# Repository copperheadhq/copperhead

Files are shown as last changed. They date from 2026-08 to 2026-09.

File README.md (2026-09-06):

<p align="center">
  <a href="https://copperhead.sh">copperhead</a>
</p>

<p align="center">
  
  
  
</p>

**Cursor for circuit boards.** An AI agent that designs, documents, and validates real PCBs from a prompt, working directly on existing KiCad repositories.

<p align="center">
  copperhead agent shell demo
</p>

> **Status: early.** Phase 1 is implemented and the CLI runs. The [technical specification](openspec/specs/SPEC.md) is the source of truth; expect the surface to move before 1.0.

Full documentation lives at [docs.copperhead.sh](https://docs.copperhead.sh).

## What it is

An AI product-development agent for hardware: from a product brief to manufacturable files, firmware, and a build plan.

- **`copperhead create`**: full pipeline from a natural-language brief: spec, architecture, part selection, schematic, first-draft layout, then gerbers, firmware scaffold, and dev plan.
- **`copperhead do "<change>"`**: operates on an existing KiCad repo the way a coding agent operates on a codebase.

It reads and edits real `.kicad_sch` / `.kicad_pcb` files (s-expression text), maintains markdown design docs as memory, propagates every change across all artifacts that reference it, and verifies its own work by running `kicad-cli` ERC/DRC until the checks pass.

## Install

> [!TIP]
> **Most users should not install copperhead by hand.** If you are working inside an AI coding assistant (like Claude Code, Cursor, or Codex), you can install and configure copperhead automatically for your repository by pasting this single line:
> ```text
> Install copperhead for this repo using https://raw.githubusercontent.com/copperheadhq/copperhead/main/agent-install-prompt.md
> ```

If you prefer to install manually:

```bash
npm install -g copperhead   # or: npx copperhead check
```

### Bootstrap script (macOS and Linux)

Prefer a one-command setup? [`install.sh`](install.sh) checks the prerequisites below, installs copperhead (globally via npm, or built from source when run inside a checkout), and verifies the result with `copperhead doctor`:

```bash
./install.sh                # interactive: asks before installing anything
./install.sh --yes          # assume yes to the install prompts
./install.sh --check-only   # report what is missing, install nothing
```

The script is conservative by design: it never runs `sudo` and never edits shell config; whenever it cannot act safely on its own it prints the exact command for you to run instead. Rerunning is safe: on a ready machine it installs nothing and exits 0.

### Requirements

- Node.js ≥ 20
- [KiCad](https://www.kicad.org/) ≥ 8 with `kicad-cli` on PATH (on Windows and macOS, copperhead also searches standard installation directories automatically; override with `COPPERHEAD_KICAD_CLI`)
- One model backend: a locally installed, ChatGPT-authenticated [Codex CLI](https://learn.chatgpt.com/docs/codex/cli), a logged-in [Cursor Agent CLI](#saved-login-cursor-agent) (`agent login`), logged-in Claude Code (see [Saved login](#saved-login-claude-code)), or `ANTHROPIC_API_KEY`/`OPENAI_API_KEY` in the environment. `check` never calls an LLM.

## Quick start

In an existing KiCad repository:

```bash
export ANTHROPIC_API_KEY=...   # or OPENAI_API_KEY; optional: with no key, `copperhead` offers a model picker
copperhead init                # scaffold docs/ from the schematic; idempotent
copperhead                     # interactive agent shell (Claude Code–style REPL)
copperhead demo --tour          # what the agent does (no LLM)
copperhead demo --model cursor # full USB-C breakout create pipeline
# or one-shot:
copperhead do "add reverse-polarity protection on VIN"
copperhead check               # ERC + DRC + doc drift; no LLM, CI-safe
```

Starting from nothing instead? Write a product brief and run `copperhead create --brief brief.md`. The [examples/](examples/) directory has ready-made briefs sorted by difficulty, plus a note on which one is designed to fail.

### Use your existing Codex login

No model API key is needed when Codex CLI is already authenticated:

```bash
npm install -g @openai/codex-sdk   # optional adapter, loaded only for --model codex
codex login status
copperhead do "rename net KEY_DAH to KEY_DASH" --model codex
```

Plain `codex` follows your Codex model configuration. Use `codex:<model-id>` for an explicit model. If the executable is not on `PATH`, set `COPPERHEAD_CODEX_PATH=/absolute/path/to/codex`.
The optional SDK also installs a compatible launcher; for a global install, use
`COPPERHEAD_CODEX_PATH="$(npm root -g)/@openai/codex/bin/codex.js"` as a fallback.

Codex's read-only sandbox prevents native writes but does not confine native reads. Copperhead instructs Codex not to use its own filesystem tools, but the CLI can technically read files such as `.env`. Codex also keeps session logs under `~/.codex/sessions/`; those files are outside Copperhead's transcript-redaction boundary and should be protected according to your local data-retention policy.

## How it works

It's a loop, and it looks a lot like pair-programming, except the codebase is a circuit board.

1. **Start from the docs.** Every decision lives in the design docs, so the agent reads those first and knows the whole design, not just the part in front of it.
2. **Talk through the change.** Describe what you want ("add an external key jack", "cut the sleep current"). The agent proposes the parts and circuit; you push back until the reasoning holds up.
3. **Edit the real files.** The agent writes changes straight into the KiCad schematic and the design docs, using the same part names and net names everywhere so nothing drifts.
4. **Propagate.** Change one value, like a charge current or a pin, and it carries across every doc and schematic that references it. The boring, easy-to-get-wrong step is the one the agent is best at.
5. **Check the work.** The agent runs ERC/DRC, reads the errors back, and fixes them. Nothing is "done" until the tools agree.
6. **Write down why.** Every real decision gets a one-line reason next to it, so the next change doesn't quietly undo it.

Two invariants make this trustworthy:

1. **Nothing starts without a spec.** The agent cannot touch a KiCad file until a validated change proposal exists; the edit tools are structurally unavailable until it does. Every edit is traceable to a documented intent.
2. **Nothing is "done" until the tools agree.** Every file mutation is followed by an ERC/DRC run before the agent reports success.

Spec-gated in, verification-gated out: the design can't drift from its requirements, because drift is a build failure.

## CLI

```text
copperhead init [--path hardware/]   # scaffold docs/ from an existing schematic; idempotent
copperhead do "<change request>"     # the core loop: propose, edit, verify, propagate, commit
copperhead skill list                # registered skills (no LLM)
copperhead skill run generate-report # read-only design report (needs a model)
copperhead check                     # ERC + DRC + doc-drift + spec validation; no LLM calls (alias: verify)
copperhead doctor                    # env preflight: node, kicad-cli, git, openspec, provider credential; no LLM/network
copperhead sync [--dry-run]          # verify the whole design state, resolve drift
copperhead create --brief brief.md   # brief → full output package
copperhead export bom --supplier jlcpcb   # supplier-ready ordering file from docs/BOM.md
copperhead mcp                       # EXPERIMENTAL: serve the gated pipeline to MCP hosts over stdio
```

Global flags: `--repo <path>` (default: cwd) and `--json` for machine-readable output. `--model` is available on `do`, `sync`, `create`, `skill run`, and `doctor`; `--interactive` only on `do` and `create`; `do` also takes `--dry-run`, `--max-turns`, and `--allow-dirty`.

`copperhead create` still uses its own hardcoded stages; those are not yet skills.

`--model` accepts `gpt-5` (OpenAI), `claude` / `claude-<id>` (Anthropic API), `claude-code` / `claude-code:<id>` (Claude Code, saved login), `cursor` / `cursor:<id>` (Cursor Agent CLI, saved login), and `codex` / `codex:<id>` (Codex CLI, saved login). Routing is by prefix; `claude-code` is matched before the `claude` prefix. `compat:<id>` targets any OpenAI-compatible endpoint (Groq, OpenRouter, Gemini, or a local Ollama) via `COPPERHEAD_BASE_URL` and `COPPERHEAD_API_KEY_ENV` - worked examples for each in [`.env.example`](.env.example) and the [configuration reference](https://docs.copperhead.sh/reference/configuration/#model-selection).

### Saved login (Cursor Agent)

`--model cursor` drives the Cursor Agent CLI with your saved login from `agent login`, so you can run copperhead with **no `OPENAI_API_KEY` or `ANTHROPIC_API_KEY`**. Cursor is used purely as a reasoning backend in plan mode: the agent loop, safety gates, and every file edit stay inside copperhead.

```bash
agent status
copperhead do "add reverse-polarity protection on VIN" --model cursor
```

If `agent` is not on `PATH`, set `COPPERHEAD_CURSOR_PATH` to the CLI binary (also available as `cursor-agent` on some installs). Cursor's JSON schema does not report token usage, so run summaries show 0 tokens for `--model cursor`.

### Saved login (Claude Code)

`--model claude-code` drives Claude Code through the [Claude Agent SDK](https://code.claude.com/docs/en/agent-sdk) and reuses your saved login (the `CLAUDE_CODE_OAUTH_TOKEN` from `claude setup-token`), so a Claude subscription runs copperhead with **no `ANTHROPIC_API_KEY`**. Claude Code is used purely as a reasoning backend: the agent loop, its safety gates, and every file edit stay inside copperhead, identical to the other providers.

```bash
claude setup-token                          # while logged into Claude Code
export CLAUDE_CODE_OAUTH_TOKEN=...           # the token setup-token printed
copperhead do "add reverse-polarity protection on VIN" --model claude-code
```

The Claude Agent SDK ships as an optional dependency, so a normal install pulls it in. copperhead loads it only when you select `claude-code`, and prints an actionable error if it is missing (for example after `npm install --omit=optional`), telling you to add it with `npm i @anthropic-ai/claude-agent-sdk`.

copperhead never reads, copies, or logs the credential; the CLI owns authentication. A missing dependency or an unauthenticated install fails with an actionable message and touches nothing.

### Ordering (`export bom`)

`copperhead export bom` turns the drift-checked `docs/BOM.md` into a file a supplier accepts without hand-editing. It is deterministic, LLM-free, and network-free, safe anywhere `check` is, and it reads `BOM.md` (never the schematic) so it inherits the drift guarantee; it refuses to export while `BOM.md` disagrees with the schematic.

```bash
copperhead export bom --supplier jlcpcb                 # JLCPCB assembly CSV → outputs/jlcpcb-bom.csv
copperhead export bom --supplier digikey --boards 25    # DigiKey cart CSV, quantities for 25 boards
copperhead export bom --supplier mouser --spares 15     # Mouser cart CSV, 15% spare parts
```

- `--supplier <jlcpcb|digikey|mouser>` (required). JLCPCB gets the assembly-service format (Comment, Designator, Footprint, LCSC Part #, designators grouped per line); DigiKey and Mouser get cart-upload lists (MPN, manufacturer, quantity, customer reference).
- `--boards <n>` (default 1) and `--spares <percent>` (default 10) set the order quantity: `ceil(perBoardCount × boards × (1 + spares/100))`, raised to `perBoardCount × boards + 2` for passive lines (footprints `R_`/`C_`/`L_`); losing a couple of 0402s to tweezers is the norm, and percentage-only spares under-order low-count passives.
- Rows without an MPN, and rows still flagged `UNVERIFIED`, are excluded from the supplier file and named in a warnings footer on stderr. `--include-unverified` opts the flagged-but-MPN'd rows back in (it never includes MPN-less rows). `create` stage 6 also emits `outputs/jlcpcb-bom.csv` automatically.

`docs/BOM.md` may carry optional `Manufacturer` and `LCSC` columns beyond the base `Refdes | Value | Footprint | MPN | Rationale`; the exporter matches columns by header, so add them when you want them populated in supplier files; `init` scaffolds the base columns only. Only *appending* columns is safe: keep `Refdes | Value | Footprint` first and in that order, because the drift check (`check`/`sync`, which the exporter gates on) reads those three by position, so reordering them makes it compare the wrong cells and refuse the export with a spurious drift message.

Nothing is a black box: decisions land in an append-only `docs/DECISIONS.md`, every run writes a human-readable summary next to its transcript, and a per-run `docs/CHANGELOG.md` narrates the design history.

## MCP server (experimental)

Coding agents are already pointed at KiCad repos through generic file tools, which
means a host agent can rewrite a `.kicad_sch` with no spec gate, no verification,
and no rollback. `copperhead mcp` closes that: it serves the gated pipeline to any
MCP host as five opaque, outcome-level tools — `copperhead_check`, `copperhead_do`,
`copperhead_sync`, `copperhead_init`, `copperhead_doctor` — and nothing finer. There is no file-edit
tool, no raw KiCad tool, and no partial-loop tool to reach around, so a host agent
cannot skip spec-gating or verification by any sequence of calls.

```jsonc
// .mcp.json
{
  "mcpServers": {
    "copperhead": {
      "command": "copperhead",
      "args": ["mcp", "--repo", "/absolute/path/to/your/kicad/project"]
    }
  }
}
```

> **The surface is experimental and unstable.** It declares a `0.` protocol major:
> tool names, inputs, and result shapes may change in any release, and there is no
> registry listing until the stabilization criteria are met. Host configuration for
> Claude Code and generic stdio hosts, the companion skill, the Codex gap, and those
> criteria are all in [`integrations/`](integrations/README.md).

`copperhead_check`, `copperhead_init` and `copperhead_doctor` need no credential; `copperhead_do` and
`copperhead_sync` with `resolve: true` refuse with a typed error naming the missing
environment variable. The server opens no network transport of its own — stdio only,
and LLM calls happen exactly where the CLI already makes them.

## What it is not

- **Not an autorouter.** Routing stays human or delegated; copperhead produces the DRC-clean draft that layout tools optimize from.
- **Not a new editor.** No walled garden; your KiCad install remains the editor.
- **Not the engineer of record.** A human signs off; the agent never claims a design is fab-ready beyond "ERC/DRC clean".

## Simple demo

From a checkout of this repo, run the smallest create-pipeline demo with the USB-C power breakout brief:

```bash
npm run demo:simple
```

The script creates or resumes a git repo at `demo-runs/usb-c-breakout/` and runs:

```bash
copperhead create --brief examples/simple/usb-c-breakout.md
```

Pass normal create flags after `--`, for example `npm run demo:simple -- --model claude`.
If a stage fails, rerun the same command; the demo repo keeps a baseline commit and ignores run transcripts so retries start from the last committed design state.

More briefs, including medium and hard tiers, live in [examples/](examples/).

## Maturity

Honest read of where the current release stands, so you can calibrate before pointing this at a board you care about:

- **Solid.** `init` and `check`/`verify` are deterministic, LLM-free, and covered by the offline test suite against a real KiCad fixture: scaffolding, ERC/DRC, the s-expression reader, drift detection, and fab export all run green in CI.
- **Implemented, not yet proven.** The agent loop (`do`, `sync --resolve`, `create`) is complete and structurally gated, but its acceptance tests need a live model and have not been observed passing end to end. Expect rough edges.
- **Always.** Every mutation runs inside a git snapshot and rolls back if verification fails, so the worst case is a no-op commit, not a mangled schematic. Work on a branch anyway.

## Open source

The entire tool (agent core, prompts, tools) is public under Apache-2.0, built on an open stack (KiCad, kicad-cli, [OpenSpec](https://github.com/Fission-AI/OpenSpec)). Everything it produces is plain markdown and JSON in your own repo: no proprietary formats, no lock-in. This is a Chouhan Industries project, and the same commitment that puts every hardware schematic in public applies to the tool that designs them.

## Contributing

Contributions are welcome; see [CONTRIBUTING.md](CONTRIBUTING.md) for setup and workflow. Note that your first pull request requires signing the [Contributor License Agreement](.github/cla/CLA.md); a bot posts instructions on the PR and signing is a one-time comment.

## Project layout

- [`AGENTS.md`](AGENTS.md): repository instructions loaded automatically by Codex and compatible coding agents; [`CLAUDE.md`](CLAUDE.md) provides the corresponding Claude Code guidance
- [`src/`](src/): CLI ([`cli.ts`](src/cli.ts), [`commands/`](src/commands/)), the provider-agnostic agent loop ([`agent/`](src/agent/)), the `kicad-cli` wrapper and s-expression reader ([`kicad/`](src/kicad/)), and doc/constraint memory ([`memory/`](src/memory/))
- [`integrations/`](integrations/README.md): MCP host configuration and the companion Claude Code skill
- [`test/`](test/): offline suite plus [`fixtures/`](test/fixtures/), a tiny known-good KiCad project
- [`openspec/specs/SPEC.md`](openspec/specs/SPEC.md): the full technical specification, including binary acceptance criteria
- [`openspec/changes/build-copperhead-phase-1/`](openspec/changes/build-copperhead-phase-1/): the implementation plan with proposal, design decisions, capability specs, and task checklist

## License

[Apache-2.0](LICENSE)

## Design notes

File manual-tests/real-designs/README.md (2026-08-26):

# Real designs

Drafting boards nobody wrote for us, and looking at the result next to the drawing a person made of the same circuit.

This is the counterpart to [reference-boards/](../reference-boards/), and the difference is what "correct" means. A reference board's golden is the engine's own pinned output, so a byte diff answers the question completely. Here the golden is a human's schematic, drawn by hand, and the engine places by its own rules. The two sheets never match byte for byte, and a diff of them says nothing at all.

So the comparison splits in two:

- **The netlist is checked by machine.** However differently the two sheets are drawn, they must join the same pins into the same nets. Every net that the source had and the draft lost, or that the draft invented, is reported.
- **The drawing is checked by eye.** Two PNGs, the person's and the engine's, of the same circuit. This is where you find out whether the output reads like a schematic or merely is one.

The designs are read from a local KiCad install at run time and the sweep's outputs land in `manual-tests/runs/` (gitignored). What IS committed lives in [examples/](examples/): the side-by-side output for boards that draft cleanly and whose licences permit redistribution, each with its licence file beside it. Boards whose licences do not permit it stay run-only; `stickhub`, for instance, is CC BY-NC-SA.

## Running it

```bash
npm run realdesigns                 # every project in the corpus
npm run realdesigns -- stickhub     # one project
COPPERHEAD_CORPUS_DIR=/path/to/projects npm run realdesigns
```

The corpus defaults to `/usr/share/kicad/demos`, which ships with KiCad and holds fifteen real projects ranging from a fifteen-part valve amplifier to a 1500-part VME board. Point `COPPERHEAD_CORPUS_DIR` at any directory of KiCad projects to use your own.

Requires `kicad-cli`. PNG rendering additionally needs ImageMagick `convert` and is best effort: some of the larger sheets defeat its default resource limits, and when that happens the schematic and netlists are still written, with a note in the output.

## What each project leaves behind

```
manual-tests/runs/real-designs/<project>/
  source.net                 netlist exported from the real project
  schematic.intent.json      the IR extracted from it
  drawn/board.kicad_sch      what the engine drafted
  back.net                   netlist exported back from the drafted sheet
  render/original*.png       the human's drawing, one PNG per sheet
  render/drawn.png           the engine's drawing
  REPORT.md                  outcome, net comparison, refusal reasons
```

Open `REPORT.md` first; it names which of the two outcomes you got and points at the renders. A refused board still gets its original render and the full finding list, so the boards the engine declines are inspectable too.

## Where the IR comes from

The input is `kicad-cli sch export netlist`, not the `.kicad_sch`. That makes KiCad flatten the hierarchy, resolve the buses, and name every net before we see it, including the ones the designer never named (`Net-(D15-1)`). Reading the schematic directly would mean re-deriving connectivity, and unnamed nets are the majority on a real board: `interf_u` has 303 of its 373 pins on nets carrying no label.

`libsource` supplies each part's lib_id and `sheetpath` supplies its group, so the extraction is deterministic with no LLM involved. The reader lives in [test/support/netlist.ts](../../test/support/netlist.ts), shared with the automated sweep so the two cannot drift.

## The automated half

`test/draft-real-corpus.test.ts` runs the same round trip as an assertion, gated on `COPPERHEAD_TEST_CORPUS=1` and skipped when no corpus is present:

```bash
COPPERHEAD_TEST_CORPUS=1 npx vitest run test/draft-real-corpus.test.ts
```

Its contract is deliberately not "every board drafts". Most real boards legitimately will not, because the engine refuses multi-unit symbols by design. The contract is the weaker and more important one: **draft faithfully or refuse legibly, never silently wrong.** A drafted sheet must partition pins exactly as the source did; a refusal must carry an attributable finding.

That test tells you whether anything broke. This directory is for looking at what the engine actually drew.

## What the corpus has found so far

Against KiCad 10.0.4's demos, eleven of fifteen boards draft with connectivity exact (the remaining four were still sweeping when this was written). Each class of refusal, once understood, became an engine or harness change:

- **Multi-unit symbols** blocked seven of fifteen projects (opamps, gate packs, multi-gang jumpers), and in all seven it was the *only* refusal (#218). The engine now places each unit as its own instance, which cleared the whole set.
- **Symbol resolution** blocked five, all boards drawn against private libraries that were never published. The harness now rebuilds those libraries from the copies every sheet embeds in its `lib_symbols` section ([test/support/embedded-libs.ts](../../test/support/embedded-libs.ts)), so they resolve without being installed; `royalblue54L_feather` and `cm5_minima` draft cleanly because of it.
- **Merged nets at routing** blocked two, `cm5_minima` (+5V shorted to GND) and `interf_u` (/PC-RD to /WR_REG), until #217. Both now draft with connectivity exact.

And the finding that only the renders could have surfaced: **the three boards that draft are correct and unreadable** (#219). All three score a composite of 40 against 85.6 to 92 for the committed reference boards, and `stickhub` carries 367 out-of-frame findings, meaning content placed outside the drawing frame. Its 94 parts come out as one horizontal ribbon on an A0 sheet that is roughly 85% empty, where the designer drew the same circuit densely on A3.

This is the reason the directory exists. The automated sweep passes all three, correctly: its contract is draft faithfully or refuse legibly, and faithfulness is not legibility. Only the side-by-side shows it.

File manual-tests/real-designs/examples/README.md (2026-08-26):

# Committed examples

Real boards the engine drafts cleanly, kept in the repo so the side-by-side comparison is browsable without installing KiCad's demos or running the sweep. Everything here is a verbatim copy of one sweep run's output: the report, the renders, the drafted schematic, and the IR the netlist reduced to.

Each example holds:

```
<board>/
  REPORT.md               outcome and netlist comparison, paths made relative
  schematic.intent.json   the IR extracted from the board's netlist
  drawn/board.kicad_sch   what the engine drafted, openable in KiCad
  render/drawn.png        the engine's drawing
  render/original*.png    the person's drawing, one per sheet
  LICENSE*                the board's own licence, where it ships one
```

## The boards, and why these

Every board here drafts with connectivity exact (lost=0, gained=0), and every one carries a licence that permits redistribution. "KiCad demo" means a board with no licence file of its own that the KiCad project distributes in the `kicad-demos` package; those are included on that provenance.

| Board | Parts | Licence |
| --- | --- | --- |
| `cm5_minima` | 84 | CERN-OHL-S 2.0 (see its `LICENSE.txt`) |
| `complex_hierarchy` | 68 | KiCad demo |
| `ecc83` | 15 | KiCad demo |
| `interf_u` | 24 | KiCad demo |
| `kit-dev-coldfire-xilinx_5213` | 160 | KiCad demo |
| `multichannel` | 114 | KiCad demo |
| `pic_programmer` | 63 | KiCad demo |
| `royalblue54L_feather` | 71 | CERN-OHL-P 2.0 (see its `LICENSE`) |
| `sonde xilinx` | 25 | KiCad demo |
| `tiny_tapeout` | 150 | Apache-2.0 (see its `LICENSE.txt`) |

These licences apply to the boards' design content, including the renders and the drafted schematic derived from it, not to the rest of this repository. `stickhub`, the other board that drafts cleanly, is CC BY-NC-SA and stays out of the repo: run `npm run realdesigns -- stickhub` to reproduce it locally.

## Regenerating

The sweep writes fresh output to `manual-tests/runs/real-designs/` (gitignored):

```bash
npm run realdesigns -- cm5_minima interf_u royalblue54L_feather
```

An example is updated by copying the run output over the committed one and making the `render/` paths in REPORT.md relative. The source projects come from the `kicad-demos` package at `/usr/share/kicad/demos`.

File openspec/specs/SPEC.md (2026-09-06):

# copperhead — Technical Specification

**Cursor for circuit boards.** An AI agent that designs, documents, and validates real PCBs from a prompt, working directly on existing KiCad repositories.

License: Apache-2.0 · Runtime: Node.js ≥ 20 · Language: TypeScript

**copperhead is open source.** The entire tool — agent core, prompts, tools, viewer — is public under Apache-2.0, developed in the open on GitHub with public issues and PRs. It builds exclusively on an open stack (KiCad, kicad-cli, OpenSpec) and produces open, inspectable artifacts: every design decision, constraint, and rationale it writes is plain markdown and JSON in the user's own repo — no proprietary formats, no lock-in, no black box. This is a Chouhan Industries project: the same commitment that puts every hardware schematic in public applies to the tool that designs them. Open source is also the distribution strategy — hardware engineers trust what they can inspect. (Commercial layer, later: hosted agent for private repos; the open core stays complete and usable forever.)

---

## 1. Product definition

### 1.1 What it is

An AI product-development agent for hardware: from a product brief to manufacturable files, firmware, and a build plan. Two modes:

**Mode A — Designer (`copperhead create`).** Input: a product description, requirements, and constraints in natural language. The agent runs the full design pipeline: spec → architecture → part selection → schematic → layout intent → verification → output package.

**Mode B — Co-designer (`copperhead do`).** Operates on an existing KiCad repository the way a coding agent operates on a codebase (the core loop, §4). Mode A is Mode B run repeatedly against a growing repo — same loop, same tools, same verification.

The agent:

- Reads and edits real `.kicad_sch` and `.kicad_pcb` files (s-expression text format)
- Maintains a set of markdown design docs ("docs-as-memory") that describe the design's intent, constraints, and rationale
- Propagates any change across every artifact that references it (schematic, BOM, pinout, docs)
- Verifies its own work by running `kicad-cli` ERC/DRC and iterating until checks pass
- Records a one-line rationale next to every decision so future changes don't silently undo past reasoning

### 1.2 What it is not

- Not an autorouter (Quilter/DeepPCB territory) — routing stays human or delegated
- Not a new editor (Flux territory) — no walled garden; the user's KiCad install remains the editor
- Not the engineer of record — human signs off; the agent must never claim a design is fab-ready beyond "ERC/DRC clean"

### 1.3 Core invariants

1. **Nothing starts without a spec.** The agent cannot touch a KiCad file until a validated OpenSpec proposal exists for the change (`openspec validate --change <id>` passes). The edit tools (`edit_file`, `write_file`) are hard-locked — not prompt-discouraged, but unavailable in the tool list — until the proposal validates. Every edit is therefore traceable to a documented intent.
2. **Nothing is "done" until the tools agree.** Every mutation of a KiCad file must be followed by an ERC (schematic) or DRC (board) run before the agent reports success. If violations exist, the agent reads the report and fixes them or explains why it cannot.

Spec-gated in, verification-gated out: the design can't drift from its requirements, because drift is a build failure.

---

## 2. Architecture

```
┌────────────┐   prompt    ┌─────────────────────────────┐
│  CLI (cmd)  ├────────────►│        Agent core           │
└────────────┘             │  provider-agnostic LLM loop │
                           │ (OpenAI / Claude / Codex)  │
                           └──────┬──────────────────────┘
                                  │ tool calls
              ┌───────────────────┼───────────────────────┐
              ▼                   ▼                       ▼
      ┌──────────────┐   ┌──────────────┐        ┌───────────────┐
      │  File tools  │   │ KiCad tools  │        │  Memory tools │
      │ read/write/  │   │ erc / drc /  │        │ design docs   │
      │ edit/search  │   │ export-svg   │        │ load/update   │
      └──────┬───────┘   └──────┬───────┘        └──────┬────────┘
             ▼                  ▼                        ▼
        .kicad_sch /       kicad-cli               docs/*.md
        .kicad_pcb         (subprocess)            BOM, pinout…
```

### 2.1 Repo layout (this project)

```
copperhead/
├── src/
│   ├── cli.ts              # entry: commander-based CLI
│   ├── agent/
│   │   ├── loop.ts         # tool-use loop, turn budget, retry
│   │   ├── providers/
│   │   │   ├── openai.ts   # GPT-5 via OpenAI SDK (tool calling)
│   │   │   ├── anthropic.ts# Claude via Anthropic SDK
│   │   │   └── codex.ts    # local Codex CLI via official SDK + saved login
│   │   ├── prompts.ts      # system prompt + task templates
│   │   └── tools.ts        # tool schemas + dispatch
│   ├── kicad/
│   │   ├── cli.ts          # kicad-cli wrapper (erc, drc, export svg)
│   │   ├── sexp.ts         # minimal s-expression reader (validation only)
│   │   ├── report.ts       # ERC/DRC .rpt / JSON parser → structured violations
│   │   ├── draft/          # deterministic drafting engine: IR → placement → routing → emission
│   │   ├── legibility.ts   # drawing-quality checker (read-only, no subprocess)
│   │   └── score.ts        # quantitative sheet score: metrics, weights, composite
│   ├── memory/
│   │   ├── scaffold.ts     # `init`: generate docs skeleton from schematic
│   │   └── drift.ts        # doc-vs-schematic consistency checker
│   ├── viewer/             # Phase 2
│   │   ├── server.ts       # express + ws, serves live board view
│   │   └── watch.ts        # chokidar watcher → re-export SVG → ws push
│   └── util/
├── test/
│   └── fixtures/           # tiny known-good KiCad project for tests
├── docs/                   # this spec, architecture notes
├── package.json            # bin: { "copperhead": "dist/cli.js" }
├── tsconfig.json
├── .env.example            # OPENAI_API_KEY= / ANTHROPIC_API_KEY= / CLAUDE_CODE_OAUTH_TOKEN=
└── LICENSE                 # Apache-2.0
```

### 2.2 Target repo layout (user's hardware project)

`copperhead init` establishes/expects this convention:

```
their-board/
├── hardware/
│   ├── <name>.kicad_pro
│   ├── <name>.kicad_sch    # possibly hierarchical, multiple sheets
│   └── <name>.kicad_pcb
├── docs/
│   ├── SPEC.md             # what the device is; top-level constraints & budgets
│   ├── BOM.md              # every part: refdes, MPN, value, package, WHY chosen
│   ├── PINOUT.md           # MCU pin assignment table + strapping/RTC notes
│   ├── SUBSYSTEMS.md       # per-sheet values & reasoning (regulator, charger…)
│   ├── BRIEF.sha256        # originating brief path + SHA-256; created on first successful spec-seed run, preserved thereafter
│   └── LAYOUT.md           # placement/routing intent: keepouts, pours, ESD placement
└── .copperhead/
    ├── config.json         # paths, model, budgets (see §5)
    └── runs/               # transcript of each `do` run (audit trail)
```

---

## 2.5 End-to-end I/O contract

### Inputs (Mode A)

```
copperhead create --brief brief.md
```

`brief.md` — the product brief, free-form markdown:

- **What it is:** "a pocket-size Morse key that types into any device as a Bluetooth keyboard"
- **Requirements:** features, interfaces (USB-C, BLE), user interactions
- **Constraints:** power budget, size envelope, unit cost target, battery life, cert targets
- **Preferences:** MCU family, connector types, no-go parts, assembly method (hand-solder vs SMT fab)

Anything unstated → the agent proposes defaults in SPEC.md and flags them `ASSUMED` for review. Ambiguity resolution is interactive: the agent asks up to N clarifying questions before starting (configurable, 0 for demo mode).

### Outputs (the deliverable package, `outputs/`)

| Artifact | Format | Produced by |
|---|---|---|
| Design docs | SPEC/BOM/PINOUT/SUBSYSTEMS/LAYOUT.md | agent (§2.2) |
| Schematic | .kicad_sch | agent edits, ERC-clean |
| Board | .kicad_pcb | agent edits, DRC-clean |
| **Gerbers + drill** | .zip (per JLC/PCBWay profile) | `kicad-cli pcb export gerbers/drill` |
| **Board outline / enclosure ref** | .dxf, .step | `kicad-cli pcb export dxf/step` |
| **Renders** | .svg (sch + pcb), 3D .png | `kicad-cli export svg`, pcb render |
| **BOM for ordering** | .csv (refdes, MPN, qty, vendor links) | generated from BOM.md |
| **Firmware scaffold** | src/ (per MCU HAL: ESP-IDF / Zephyr / Arduino) | agent, compiles clean |
| **Pin map header** | pins.h — generated from PINOUT.md, single source of truth | drift-checked |
| **Dev plan** | DEVPLAN.md: bring-up steps, test points, what to meter first, risk list, prototype order plan | agent |

Firmware scope: scaffold + pin definitions + driver stubs + one working happy-path (e.g. key press → BLE HID report). "Compiles clean against the vendor toolchain" is the verification gate — same philosophy as ERC/DRC: nothing is done until the toolchain agrees.

### The pipeline (Mode A internally)

**Run-to-completion guarantee:** once `create` starts, it always finishes with the complete output package. Gates are *quality checks the agent must satisfy*, not stops that wait for a human. By default the pipeline is fully autonomous: unstated decisions get `ASSUMED` flags, imperfect layout gets the `Draft quality` label, and the run ends with gerbers, firmware, renders, and DEVPLAN.md on disk — an end product, reviewable as a whole. `--interactive` turns the two human gates (spec approval, pre-export review) back on for users who want them.

```
brief.md
  → SPEC.md (budgets, ASSUMED flags)          [gate: spec is self-consistent]
  → architecture (block diagram in SUBSYSTEMS.md)
  → part selection (BOM.md with rationale)     [gate: check_drift]
  → schematic, sheet by sheet                  [gate: ERC after every sheet]
  → first-draft layout (see below)             [gate: DRC]
  → outputs package                            [gate: all exports succeed]
  → firmware scaffold                          [gate: build passes]
  → DEVPLAN.md
```

Each stage is a `do`-loop run with a stage-specific prompt. State lives in the repo (docs + files), so `create` is resumable: kill it at any stage, re-run, it continues from the docs.

### First-draft layout (explicitly non-optimal, explicitly useful)

The agent produces an **initial placement and routing plan** — correct, not optimal — and says so:

- **Placement:** rule-driven, from LAYOUT.md intent: connectors on edges, decoupling caps at their IC pins, ESD at connectors, antenna keepout honored, crystal next to MCU, user-facing parts (buttons, LEDs) where the brief puts them. Written as actual coordinates into the .kicad_pcb.
- **Routing:** power nets and short critical nets routed by rule (USB differential pair length-matched via KiCad's tools where possible); remaining nets left as ratsnest or routed naively. Every routed net must pass DRC; nothing hand-wavy.
- **Honesty gate:** LAYOUT.md gets a `## Draft quality` section auto-written by the agent, listing exactly what is fine (budgets, keepouts, DRC-clean) and what a human or a specialist tool (Quilter, autorouter) should redo before fab. Non-optimal is acceptable; unlabeled non-optimal is not.
- **Positioning:** this makes layout tools *complements, not competitors* — copperhead produces the DRC-clean draft and constraints file they optimize from.

Delta 4 framing: a first-draft board that passes DRC in an hour vs. a blank canvas that takes a specialist a week. Optimization is iteration; the blank canvas was the bottleneck.

## 2.6 OpenSpec integration — the documentation layer

copperhead adopts [OpenSpec](https://github.com/Fission-AI/OpenSpec) (spec-driven development framework, Node ≥ 20 — same runtime) as the user-facing docs/change-management layer on top of the design docs.

### Two-tier memory model

| Tier | Location | Owner | Contents |
|---|---|---|---|
| **Spec tier (OpenSpec)** | `openspec/specs/` | user-reviewable truth | Requirements & scenarios per capability: power, connectivity, ui, enclosure, firmware. What the product must do and under what constraints |
| **Design tier (copperhead)** | `docs/` + `.copperhead/` | agent working memory | How it's achieved: BOM rationale, pinout, subsystem values, layout intent — plus the machine-readable constraint memory (below) |

### Constraint memory

The agent maintains `.copperhead/constraints.json` — a live, machine-readable registry built **simultaneously with the docs**: every time a constraint is stated (brief), assumed (flagged `ASSUMED`), or discovered (datasheet), it lands in both the human doc and the registry in the same tool turn:

```json
{
  "power.sleep_current_uA":  { "max": 25,  "source": "openspec/specs/power/spec.md#R2",
                               "affects": ["U2", "R7-absent", "GPIO-pullups"] },
  "rf.antenna_keepout_mm":   { "min": 5,   "source": "docs/LAYOUT.md", "affects": ["zone:top"] },
  "pins.strapping":          { "forbidden": ["GPIO0","GPIO3","GPIO45","GPIO46"],
                               "source": "esp32-s3 datasheet §2.4" }
}
```

Loaded into every run's system prompt; `check` validates the design against it mechanically where possible (leakage sums, keepout geometry, forbidden pins). The `affects` field is what makes propagation reliable — change a constraint and the agent knows exactly which parts to revisit.

An `affects` item that targets an artifact that does not exist yet (schematic, board, or BOM recorded before their pipeline stage) opens no revisit obligation at record time — it is marked `deferred` in the registry instead, and the obligation re-opens automatically at the start of the first run where the artifact exists. This keeps early docs-only stages from burning turns on ceremonial "not yet created" resolutions without losing the reconciliation guarantee: the revisit still happens, at the moment it can actually change the design.

### Change workflow (OpenSpec propose → apply → archive)

- `copperhead do "<request>"` first generates `openspec/changes/<id>/` (proposal.md, spec deltas, tasks.md), then implements against it; the ERC/DRC-clean commit archives the change. Every hardware change gets a paper trail: *why → what spec changed → what files changed → verification result*
- `copperhead create` seeds `openspec/specs/` from the brief as stage one — requirements with scenarios ("Given the device sleeps, when idle 1 year, then battery ≥ 20%") become the testable source that SPEC.md budgets derive from
- In `--interactive` mode, the human approves the proposal; in autonomous mode it's written and auto-approved with an `AUTO` marker — reviewable after the fact, never lost
- `openspec validate` runs inside `copperhead check`

### Trigger mechanics

OpenSpec is never user-triggered; copperhead drives it as subprocess tools (same pattern as kicad-cli):

| When | copperhead runs | Effect |
|---|---|---|
| `init` / `create` start | `openspec init` (once) | Scaffolds `openspec/`; agent seeds `specs/` from the brief |
| `do` — plan step | agent writes `openspec/changes/<id>/`, then `openspec validate --change <id>` | **Edit tools stay locked until the proposal validates.** The plan step *is* the proposal |
| `do` — after ERC/DRC pass + commit | `openspec archive <id>` | Deltas merge into `specs/`; change record closed by the same code path that committed |
| `check` | `openspec validate` | Part of the standard gate set |
| `--interactive` only | pause after proposal validation | Human y/n before edits unlock — the single manual trigger |

This kills the last "docs drift" failure mode: requirements (openspec) → budgets (SPEC.md) → constraints (constraints.json) → design (KiCad) form a chain where every link is checked by tooling, not memory.

## 3. CLI surface (Phase 1)

```
copperhead [repl] ["<change request>"] [--model …] [--allow-dirty]
    Interactive agent shell (default when no subcommand is given).
    Claude Code–style prompt loop on a TTY: each line runs one
    `do`-equivalent change (same gates, including the AC-3.8 dirty-tree
    refusal and the same off-by-default `--allow-dirty` escape hatch),
    then returns to the prompt.
    Slash commands: /help, /demo, /examples, /status, /check, /parts, /nets,
    /bom, /sync, /drift, /constraints, /openspec, /config, /git, /runs, /last,
    /model, /version, /clear, /quit. Inspect commands are verify-only (no LLM
    resolve / create). An optional first request runs before the loop. Non-TTY
    without a request refuses and points at `copperhead do`. With no model
    configured anywhere, a TTY session offers an interactive picker (also
    reachable later via /model). Session output mirrors to
    `.copperhead/runs/repl-<ts>.log` with AC-4.1 redaction applied.

copperhead demo [--tour] [--model …] [--dir <path>]
    Print a short tour of what the agent does (`--tour`), or scaffold
    `demo-runs/usb-c-breakout/` and run the create pipeline against the
    packaged USB-C power breakout brief (same as `npm run demo:simple`).

copperhead create --brief brief.md   # Mode A: full pipeline (§2.5)
copperhead init [--path hardware/]
    Detect .kicad_sch/.kicad_pcb, parse symbols/footprints/nets,
    generate docs/ skeleton pre-filled with the real BOM and pinout
    extracted from the schematic. Idempotent; never overwrites
    hand-edited docs without --force.

copperhead draft schematic [--json]
    Deterministically draft the schematic from its declared intent
    (schematic.intent.json): the engine computes every coordinate, wire,
    label, power symbol, and group box. No LLM, no network. Exits non-zero
    with numbered findings on a refused intent and writes nothing.

copperhead score schematic [--json]
    Quantitative drawing-quality score for the sheet: per-metric breakdown,
    weights, contributions, and the composite. Advisory only — the exit code
    is 0 regardless of the composite. No LLM, no network.

copperhead do "<change request>" [--model codex|gpt-5|claude] [--max-turns N]
    The core loop. See §4.

copperhead skill list
    Print registered skills and whether each is available. LLM-free, network-free,
    and does not create a run transcript/directory.

copperhead skill run <name> [--scope power|all] [--model …]
    Run a skill (currently `generate-report`) via the nested sub-run. Needs a
    model, same as `do`. Does not snapshot or commit.

copperhead check          (alias: copperhead verify)
    Run ERC + DRC + doc-drift check; exit non-zero on violations.
    No LLM calls. Usable as CI step / pre-commit hook.

copperhead sync [--dry-run]
    Verify the entire design state for inconsistencies — doc tables vs
    schematic, constraints.json vs docs and openspec specs, PINOUT.md vs
    pins.h, DECISIONS/CHANGELOG coverage — then resolve the drift via a
    spec-gated agent run (same gates as `do`). Truth precedence: KiCad
    files are ground truth for as-built facts; openspec specs and SPEC.md
    budgets are ground truth for requirements. An inconsistency that
    implies a requirement violation is flagged for the human, never
    silently rewritten. `--dry-run` prints the full inconsistency report
    and writes nothing. Idempotent: a second run finds nothing to do.

copperhead mcp [--repo <path>]            # EXPERIMENTAL
    Serve the gated pipeline to MCP hosts over stdio as five opaque,
    outcome-level tools (copperhead_check / _do / _sync / _init / _doctor).
    No file-edit, raw-KiCad, or partial-loop tool is exposed, so a host
    agent cannot skip spec-gating or verification by any sequence of
    calls; every mutating tool runs the same loop the CLI runs. The
    surface declares a `0.` protocol major and is unstable: tool names,
    inputs, and result shapes may change in any release. stdio only — the
    server opens no network transport, and LLM calls happen exactly where
    the CLI already makes them.

copperhead explain <refdes|net|pin>       # stretch
    Answer "why is R7 here?" from docs + schematic context.

copperhead watch                          # Phase 2
    Start the live viewer (see §6).
```

Global flags: `--repo <path>`, `--dry-run` (propose diff, don't write), `--json` (machine-readable output).

---

## 4. The agent loop (`copperhead do`)

### 4.0 The workflow in plain words (canonical description — use in README/pitch)

It's a loop, and it looks a lot like pair-programming, except the codebase is a circuit board.

1. **Start from the docs.** Every decision lives in the design docs, so the agent reads those first and knows the whole design, not just the part in front of it.
2. **Talk through the change.** Describe what you want ("add an external key jack", "cut the sleep current"). The agent proposes the parts and circuit; you push back until the reasoning holds up.
3. **Edit the real files.** The agent writes the changes straight into the KiCad schematic and the design docs, using the same part names and net names everywhere so nothing drifts.
4. **Propagate.** Change one value, like the charge current or a pin, and it carries across every doc and the schematic that references it. This is the boring, easy-to-get-wrong step the agent is best at.
5. **Check the work.** The agent runs ERC/DRC, reads the errors back, and fixes them. Nothing is "done" until the tools agree.
6. **Write down why.** Every real decision gets a one-line reason next to it, so the next change doesn't quietly undo it.

§4.1 below is this loop made precise; §2.6 adds the OpenSpec proposal wrapper around steps 1–2 and the constraint registry behind steps 4–5.

### 4.1 Sequence

1. **Load memory.** Read all `docs/*.md` + the schematic file list into the system context. Docs are small by design (< ~2k lines total); include them whole.
2. **Plan.** Agent states, in one short block: what will change, which files are affected, which constraints are at risk (e.g. sleep-current budget).
3. **Edit.** Agent uses tools to modify KiCad files and docs. Edits to `.kicad_sch`/`.kicad_pcb` are **text edits on the s-expression source** (search/replace with context anchors) — no full-file regeneration, ever. Same net names and refdes everywhere.
4. **Verify.** Agent runs `run_erc` (always) and `run_drc` (if the .kicad_pcb changed). Parses violations.
5. **Repair.** If violations: fix and re-run, up to `maxRepairCycles` (default 5). If still failing: revert to the pre-run snapshot and report failure with the violation list.
6. **Propagate.** Agent runs `check_drift`; any doc that references a changed value/part/pin must be updated in the same run.
7. **Rationale.** Every non-trivial decision gets a one-line "why" written into the relevant doc.
8. **Commit.** `git commit` with a structured message (`copperhead: <request>\n\n<summary of edits + verification result>`). Requires clean working tree at start (§7 safety).

### 4.2 Tool schemas

| Tool | Signature | Notes |
|---|---|---|
| `read_file` | (path) → text | Repo-relative, sandboxed to repo root |
| `edit_file` | (path, old_string, new_string) → ok | Exact-match anchored replace; fails if not unique |
| `write_file` | (path, content) → ok | New files only (docs); refuses to overwrite .kicad_* |
| `search` | (regex, glob?) → matches | ripgrep-style over repo |
| `list_symbols` | (sch_path) → [{ref, value, footprint, sheet}] | From s-expression parse |
| `list_nets` | (sch_path) → [net names] | |
| `run_erc` | () → {violations: [...]} | `kicad-cli sch erc --format json --exit-code-violations` |
| `run_drc` | () → {violations: [...]} | `kicad-cli pcb drc --format json --exit-code-violations` |
| `export_svg` | (sch\|pcb) → path | For viewer + before/after diffing |
| `check_drift` | () → [{doc, claim, actual}] | Compares doc tables (BOM/pinout) against parsed schematic |
| `generate_report` | (scope?: power\|all) → report | Skill: nested read-only sub-run; ERC/DRC/drift/nets. Always in the catalog. |

### 4.3 System prompt — key rules (verbatim requirements)

- You are a hardware design agent working on real KiCad source files. Edit s-expressions surgically; never regenerate a whole file.
- You cannot edit any file until your change proposal validates (§1.3 invariant 1). Write the proposal first; the edit tools appear only after it passes.
- The design docs are the memory. Read them before proposing anything; update them with everything you change.
- Hold **all** constraints simultaneously: electrical budgets (e.g. sleep current), voltage ranges, package availability, strapping pins, RTC-capability, antenna keepouts. A part that satisfies the obvious constraint but violates a budget is a bug.
- Check the MCU strapping table before assigning any pin. Check quiescent/leakage current of every part against the power budget in SPEC.md.
- Nothing is done until ERC (and DRC when applicable) passes. Read the violation report; do not guess.
- Write a one-line rationale next to every decision. If you remove a part, record why the absence is intentional (a missing pullup can look like a mistake).
- If a request would violate a documented budget or constraint, stop and say so — do not silently comply.

### 4.4 Provider abstraction

```ts
interface Provider {
  chat(messages: Msg[], tools: ToolSchema[], opts): Promise<Turn>;
}
```

- `openai.ts`: GPT-5 via chat completions + tool calling (hackathon shared key)
- `anthropic.ts`: Claude via messages API + tool use
- `codex.ts`: locally installed Codex CLI via the official SDK and saved `codex login` authentication; Codex runs read-only and returns structured Copperhead tool requests
- `claude-code.ts`: saved-login Claude Code via the Claude Agent SDK: a reasoning-only backend (no SDK tools, built-ins disabled, isolated cwd) mapped onto the single-turn `Provider` seam so the loop stays the driver. Selected by `--model claude-code` / `claude-code:<id>` (routed ahead of the `claude*` prefix); needs no `ANTHROPIC_API_KEY` (uses `CLAUDE_CODE_OAUTH_TOKEN` / the logged-in CLI); never falls back to a keyed provider. `@anthropic-ai/claude-agent-sdk` ships as an `optionalDependency` (its `@anthropic-ai/sdk >=0.93.0` peer is satisfied by copperhead's bumped core SDK), lazily imported and only loaded when `claude-code` is selected.
- `cursor.ts`: saved-login Cursor Agent CLI subprocess (`agent login`), reasoning-only (plan mode, sandbox, isolated workspace, JSON tool protocol, session resume via `--resume`). Selected by `--model cursor` / `cursor:<id>`; needs no model API keys; never falls back to a keyed provider. Optional `COPPERHEAD_CURSOR_PATH` (default `agent` on PATH).
- `openai.ts` compatible-endpoint mode: `--model compat:<id>` points the same provider at any OpenAI-compatible endpoint (Groq, OpenRouter, Gemini's compat endpoint, a local Ollama) via `baseURL` + `apiKeyEnv` (config, or `COPPERHEAD_BASE_URL` / `COPPERHEAD_API_KEY_ENV`). Only the `compat` route reads `baseURL`, so a stray value never redirects a `gpt-5` run; a loopback endpoint needs no credential.
- Selection: `--model` flag > `COPPERHEAD_MODEL` env > config.json > the available key, but **only when exactly one of `OPENAI_API_KEY`/`ANTHROPIC_API_KEY` is set**; with two or more present and no explicit selection, resolution refuses with an actionable error rather than silently favoring one (breaking change from "first key wins")
- All providers must pass the same integration test on the fixture repo

### 4.5 Budgets & failure modes

- `maxTurns` default 40; `maxRepairCycles` 5; per-run token budget logged
- On turn-budget exhaustion in an attended (TTY) run: print run stats (turns, files touched, open obligations, token usage) and ask whether to continue with more turns; declining, or a non-TTY run, fails as below. The extension can repeat; each is a fresh decision with fresh numbers.
- On any unrecoverable failure: preserve the touched work as a git stash entry named `copperhead failed run <run-id>`, restore the snapshot, print the stash ref and transcript path, exit 1
- Rate-limit (429): exponential backoff ×3, then fail over to the other **keyed** provider (`openai` ↔ `anthropic`) if a key exists; saved-login providers (`codex`, `claude-code`, `cursor`) never fail over to a keyed or alternate provider
- Nested skill provider turns use the same bounded timeout and 429 backoff policy. A provider error inside a skill becomes a failed tool envelope, so it cannot escape the parent loop and bypass its failure/rollback path.
- The Anthropic provider marks `cache_control` breakpoints (system prompt, last tool, last message block) so the resent conversation prefix is cached; reported input tokens include cache reads/writes

---

## 5. Config (`.copperhead/config.json`)

```json
{
  "schematic": "hardware/open-telegraph.kicad_sch",
  "board": "hardware/open-telegraph.kicad_pcb",
  "docs": "docs/",
  "model": "gpt-5",
  "maxTurns": 40,
  "stageMaxTurns": { "spec-seed": 60 },
  "budgets": { "sleep_current_uA": 25 }
}
```

`budgets` is free-form; keys are surfaced verbatim into the system prompt so the agent treats them as hard constraints. `stageMaxTurns` is optional: per-stage turn budgets for the create pipeline, keyed by stage name; stages without an entry use `maxTurns`.

---

## 6. Phase 2 — Live viewer (`copperhead watch`)

The "Cursor feel": see the board change as the agent works.

- Express server on `localhost:3663`, single-page app (no build step; one HTML file)
- Left pane: chat input → runs `copperhead do` in-process, streams agent turns (plan / edits / verify) over WebSocket
- Right pane: schematic + board SVG, re-exported via `kicad-cli ... export svg` after every file mutation (chokidar watcher), pushed over WS, pinned zoom/pan preserved across reloads
- Status bar: ERC/DRC state (red/amber/green), last-run rationale lines
- Before/after: keep the pre-run SVG; toggle to flick between them

Acceptance: type "add a second RGB LED on an RTC-capable pin" → watch schematic re-render + ERC flip green, with no manual refresh.

## 7. Safety rails

- Refuse to run `do` or `repl` on a dirty git tree (offer `--allow-dirty`, whose snapshot pairs a `git stash create` object for tracked changes with a tree object for untracked files, so the rollback restores both rather than letting `git clean` delete what the stash never captured). An untracked file that exists but cannot be read refuses the run by name: it cannot be snapshotted, and the rollback would delete it regardless, so proceeding would break exactly the promise `--allow-dirty` makes. Untracked paths that vanish before the snapshot is taken are skipped rather than refused
- All file tools sandboxed to repo root; no network tools in Phase 1
- Every rail above applies identically to the MCP entry point (`copperhead mcp`), which is a transport adapter over the same command entry points and adds no privileges of its own. Any path a host supplies is contained to the repo root by `resolveInRepo` before use, exactly as a CLI-supplied path is
- `.env` in `.gitignore` from first commit; keys only via env vars — never written to any file, transcript, or commit
- Transcripts in `.copperhead/runs/` redact anything matching `sk-[A-Za-z0-9_-]+`
- The Codex CLI's native read access and `~/.codex/sessions/` logs are outside Copperhead's enforcement/redaction boundary; the Codex path documents this host-local exposure explicitly
- The agent never invents MPNs: any new part must come with a datasheet-verifiable justification in BOM.md, flagged `UNVERIFIED` for human review

## 8. Phase 3 — Integrations (post-hackathon roadmap; document, don't build)

- **CI**: GitHub Action running `copperhead check` (ERC + DRC + drift) with a badge — hardware repos get a green check like software
- **Simulation checkers**: ngspice (analog sanity), openEMS (EMC) as additional verify tools — architecture is checker-agnostic
- **KiCad plugin**: chat panel inside KiCad via the IPC API — the full-Cursor endgame
- **Part data**: live availability/pricing (Octopart/JLC), so "sourceable" becomes a checked constraint
- **Format expansion**: Altium file support; the agent core is format-agnostic, only tools change
- **Hosted**: private-repo SaaS, per-seat; payments via merchant-of-record (Dodo)

## 9. Acceptance criteria

Format: Given / When / Then. "Fixture" = the open-telegraph repo (or the tiny test project in `test/fixtures/`). All criteria are binary — they pass or they don't.

### AC-1 · `copperhead init`

- **AC-1.1** Given a KiCad repo with no `docs/`, when `copperhead init` runs, then `docs/SPEC.md`, `BOM.md`, `PINOUT.md`, `SUBSYSTEMS.md`, `LAYOUT.md` and `.copperhead/config.json` exist.
- **AC-1.2** BOM.md contains one row per schematic symbol with real refdes, value, and footprint parsed from the `.kicad_sch` — not placeholders. Row count equals `list_symbols` count.
- **AC-1.3** PINOUT.md contains the MCU's actual pin-to-net assignments parsed from the schematic.
- **AC-1.4** Re-running `init` on the same repo exits 0 and changes no hand-edited file (idempotent). With modified docs and no `--force`, it refuses and lists what it would overwrite.
- **AC-1.5** On a repo with no `.kicad_sch`, exits non-zero with a clear message (no stack trace).

### AC-2 · `copperhead check`

- **AC-2.1** On a clean fixture: exit 0, prints ERC ✓ DRC ✓ drift ✓, makes zero LLM calls (assert: no network to api.* hosts).
- **AC-2.2** With a deliberately broken schematic (unconnected pin): exit non-zero, violation printed with sheet/location.
- **AC-2.3** With a BOM.md value edited to disagree with the schematic (e.g. wrong resistor value): drift check fails and names the doc, the claim, and the actual value.
- **AC-2.4** `--json` emits machine-readable results (parseable, stable keys).
- **AC-2.5** Runs in < 60 s on the fixture.

### AC-3 · `copperhead do` — core loop

- **AC-3.1 (rename)** `do "rename net KEY_DAH to KEY_DASH"` → net renamed in every sheet it appears; PINOUT.md and SUBSYSTEMS.md updated; ERC exit 0; exactly one commit; no other net or doc line changed (diff inspected).
- **AC-3.2 (constraint reasoning)** `do "move the key input to a different RTC-capable pin"` → chosen pin is RTC-capable AND not a strapping pin (GPIO0/3/45/46 on ESP32-S3); transcript shows the strapping table was consulted; schematic + PINOUT.md agree; ERC exit 0.
- **AC-3.3 (add part)** `do "add a second RGB LED"` → new symbol with unique refdes, valid footprint from the existing library set, net connected to a real GPIO; BOM.md gains a row with MPN flagged `UNVERIFIED` and a one-line rationale; ERC exit 0.
- **AC-3.4 (budget refusal)** `do "add a 100kΩ pullup on KEY_DAH"` (which would leak ~33 µA against the 25 µA budget) → agent **refuses or proposes an alternative**, citing the budget from SPEC.md. It must not silently comply. This is the money demo.
- **AC-3.5 (repair loop)** Given an edit that first produces an ERC violation, the transcript shows: violation parsed → targeted fix → re-run → pass, within `maxRepairCycles`.
- **AC-3.6 (rollback)** If violations persist after `maxRepairCycles`, working tree equals the pre-run state (`git status` clean, files byte-identical), exit non-zero, transcript path printed.
- **AC-3.7 (surgical edits)** For every run above: the `.kicad_sch` diff touches only the s-expressions relevant to the change — file not regenerated (assert: < 5% of lines changed for AC-3.1).
- **AC-3.8 (dirty tree)** With uncommitted changes and no `--allow-dirty`: refuses to start. Holds for `repl` as well as `do`, since `repl` is the default command. With `--allow-dirty`, a rollback restores both the tracked modifications and the untracked files that were present before the run.
- **AC-3.9 (dry run)** `--dry-run` prints the proposed diff and writes nothing.
- **AC-3.10 (provider parity)** AC-3.1 passes with `--model codex`, `--model gpt-5`, `--model claude`, `--model claude-code`, `--model cursor`, and `--model compat:<id>` when each provider is configured.
- **AC-3.11 (saved login)** With `--model claude-code`, a logged-in Claude Code (`CLAUDE_CODE_OAUTH_TOKEN` set) and **no** `ANTHROPIC_API_KEY`/`OPENAI_API_KEY`, a `do` run completes through the normal verify/commit path; copperhead reads no credential store; and no key material appears in the transcript, summary, or tree (AC-4.1 holds). A missing optional dependency or an unauthenticated install fails through the rollback path with an actionable error, not a raw stack trace.
- **AC-3.12 (cursor saved login)** With `--model cursor`, a logged-in Cursor Agent CLI (`agent login`) and **no** model API keys, a `do` run completes through the normal verify/commit path; copperhead never reads Cursor credentials; unauthenticated or missing CLI installs fail with an actionable message and rollback.
- **AC-3.13 (compat credential resolution)** With `baseURL` and `apiKeyEnv` configured (via `.copperhead/config.json` or `COPPERHEAD_BASE_URL`/`COPPERHEAD_API_KEY_ENV`) and the named variable set, `--model compat:<id>` issues its requests to that endpoint using that credential; a credential present under a different variable name does not satisfy it.
- **AC-3.14 (compat locality)** A `baseURL` resolving to a loopback host (`localhost`, `127.0.0.1`, `::1`, or a `.local` suffix) requires no credential; a remote `baseURL` without its configured credential fails before any network call, naming the missing variable in the error.
- **AC-3.15 (compat routing is explicit)** Bare `compat` (no model id) and `compat:` (empty model id) are both rejected with an actionable message naming `compat:<model-id>`; a compatible endpoint has no default model to fall back to, unlike `codex`/`claude-code`/`cursor`.
- **AC-3.16 (compat endpoint isolation)** An exported `COPPERHEAD_BASE_URL`/`COPPERHEAD_API_KEY_ENV` does not change where a non-`compat` model (`gpt-5`, `claude`, etc.) sends its requests; only the explicit `compat:` prefix consults them.
- **AC-3.17 (compat prompt-privacy signal)** `doctor` reports a non-blocking `warn` line when the compat endpoint's host is documented as training on submitted prompts, and a non-blocking `info` line naming the host when no policy is on record; neither case fails the command. A true loopback endpoint (`localhost`, `127.0.0.1`, or `::1`, but not a `.local`/LAN host) bypasses this check entirely, since nothing leaves the machine.
- **AC-3.18 (compat never fails over to a paid key)** A rate limit against a `compat:<id>` endpoint never fails over to `OPENAI_API_KEY`/`ANTHROPIC_API_KEY`, even when one is present in the environment: the compat provider is not `'openai'` by name, so the same isolation that protects `codex`/`claude-code`/`cursor` (AC-3.11, AC-3.12) applies to it too.
- **AC-3.19 (ambiguous auto-selection refuses)** With no `--model`, no `COPPERHEAD_MODEL`, and no `model` in config, model resolution refuses with an actionable "ambiguous" error naming every credential found when two or more of `OPENAI_API_KEY`/`ANTHROPIC_API_KEY` are set; with exactly one, that provider is selected as before. **Breaking change**: an environment with both keys set that previously auto-selected `OPENAI_API_KEY` now fails `do`/`sync`/`create`/`demo` until a model is chosen explicitly (`repl` degrades gracefully via its interactive picker instead).
- **AC-3.20 (compat cache is endpoint-scoped)** Re-running a cached `compat:<id>` request against a different `baseURL` calls the new endpoint rather than replaying the previous one's turns: one model id can be served by several hosts, so the id alone no longer identifies the backend. The endpoint enters the cache key only for the `compat` route, so a non-`compat` run's existing cache entries still replay unchanged.

### AC-4 · Safety

- **AC-4.1** No file in the repo, transcript, or any commit ever contains a string matching `sk-[A-Za-z0-9_-]{20,}` (grep the whole tree + `.copperhead/runs/` after all tests).
- **AC-4.2** A tool call with a path outside the repo root (e.g. `../../etc/hosts`) is rejected.
- **AC-4.3** `.gitignore` includes `.env` and `.copperhead/runs/` in the very first commit of the repo.

### AC-7 · `copperhead sync` — full-state consistency

- **AC-7.1 (resolve doc drift)** With BOM.md edited to disagree with the schematic, `sync` updates the doc to match the as-built schematic, appends a DECISIONS.md entry and a CHANGELOG.md entry, commits once, and exits 0; a `check` run immediately after is clean.
- **AC-7.2 (repair dual-write)** With a constraint stated in a doc but missing from `constraints.json`, `sync` adds the registry entry with the correct `source` and `affects`, and vice versa (registry entry with no doc mention gets the doc line).
- **AC-7.3 (never resolve a violation silently)** With an inconsistency that reflects a requirement violation (e.g. a part whose leakage breaks the sleep-current budget), `sync` does **not** rewrite either side to agree; it flags the violation with both sides and the governing spec/budget, and exits non-zero.
- **AC-7.4 (dry run)** `sync --dry-run` prints every detected inconsistency (doc, claim, actual, proposed resolution) and writes nothing (`git status` unchanged).
- **AC-7.5 (clean and idempotent)** On a consistent repo, `sync` exits 0 with "no inconsistencies", makes no edits and no commit; running `sync` twice in a row makes the second run a no-op.

### AC-15 · Turn-budget continue & loop efficiency (issue #15)

- **AC-15.1 (continue)** When `maxTurns` is reached in an attended run, granting extra turns continues the conversation from the same state, records a `budget-extended` transcript event, and the run can still succeed.
- **AC-15.2 (decline)** Declining at the prompt fails and restores the snapshot exactly as before.
- **AC-15.3 (non-interactive unchanged)** With no callback (CI, pipes), exhaustion fails and restores exactly as before.
- **AC-15.4 (cost visible)** The decision point shows turns used, files touched, open obligations, and cumulative tokens in/out.
- **AC-15.5 / AC-15.6 (batching guidance)** The system prompt workflow and the 5-turns-remaining nudge both instruct emitting multiple independent tool calls per response.
- **AC-15.9 / AC-15.10 (batch resolution)** `resolve_affected` accepts `resolutions: [...]`; entries resolve independently with per-entry results.
- **AC-15.12 / AC-15.13 (convergence feedback)** `run_erc`/`run_drc` without a configured artifact read as not-applicable-yet; `search` rejects an empty pattern with a corrective hint. (Obligation deferral for not-yet-built artifacts is provided by the persisted constraint-registry mechanism in AC-8's change, not re-implemented here.)
- **AC-15.14 / AC-15.15 (prompt caching)** The Anthropic provider sends three `cache_control` breakpoints (system, last tool, last message block) and counts cache-read/creation tokens in reported input usage.
- **AC-15.16 / AC-15.17 (work preservation)** Any run failure with touched files leaves a `copperhead failed run <run-id>` stash entry holding the work while the tree is restored byte-identical; a clean failure leaves no stash.
- **AC-15.18 / AC-15.19 (per-stage budgets)** `stageMaxTurns` in config overrides `maxTurns` for named create-pipeline stages; absent entries change nothing.
- **AC-15.20 – AC-15.22 (edit validation)** An `edit_file` that makes a loadable `.kicad_sch`/`.kicad_pcb` unloadable is reverted with kicad-cli's error; `.kicad_pro`/`.kicad_sym`/`.kicad_mod` edits are never probed or reverted; an already-unloadable file keeps repair edits.
- **AC-15.23 / AC-15.24 (content-aware completion)** The schematic stage completes only with symbols present and drift-clean BOM/PINOUT (layout-draft: a board with a footprint plus the LAYOUT.md marker); a successful run that leaves the contract unmet halts the pipeline for resume instead of advancing.
- **AC-15.25 / AC-15.26 (drift bootstrap)** Zero-symbol schematics produce no drift mismatches; `check` surfaces a non-failing warning when an empty schematic coexists with a populated BOM.md.
- **AC-15.27 (consecutive stalls)** Only consecutive tool-less turns count toward the stopped-without-finishing failure; the counter resets on any tool call.
- **AC-15.28 (load-failure ERC/DRC)** A missing ERC/DRC report raises an error quoting kicad-cli's own output and naming the likely load failure.
### AC-8 · Run observability (change: record-run-metadata)

- **AC-8.1 (metadata completeness)** The `run-start` event of any agent-loop run contains: copperhead version + install path, `kicad-cli`/Node/platform versions, model id + provider + selection source (`flag`/`env`/`config`/`openai-key`/`anthropic-key`), run id + ISO timestamp + command, interactive flag, the resolved config snapshot (`schematic`, `board`, `docs`, effective `maxTurns`, `maxRepairCycles`, `budgets`), git commit/branch/dirty + uncommitted count, pre-commit-hook presence, and open-constraint + prior-run counts. The pre-existing `request`/`model`/`provider` fields keep their names. Collection is LLM-free and network-free.
- **AC-8.2 (resolved, not raw)** `do "x" --max-turns 12` in a repo whose config says `maxTurns: 40` records turn budget **12**, and the selection source names the actual winner of flag > `COPPERHEAD_MODEL` > config > key-fallback. A repo with no schematic records `schematic: null` (key present).
- **AC-8.3 (probe degradation)** A failing environment probe (e.g. git branch unavailable) yields `null` for that field only; all other fields populate and the run proceeds — a metadata failure never aborts or alters a run.
- **AC-8.4 (three surfaces, one source)** `summary.md` contains an `## Environment` section whose values match the `run-start` event, and the CLI prints a header of ≤ 2 lines before the first turn showing at minimum: version, model + provider + selection source, stage `name (k/N)` when in a `create` pipeline, and turn budget.
- **AC-8.5 (run-end addenda on every path)** Every terminal branch (success, refusal, turn-budget, repair-cycles, provider error, stall, commit failure) emits a `run-end` event and a `## Run stats` summary section with: exit path (`done`/`refused`/`turn-budget-exhausted`/`repair-cycles-exhausted`/`commit-failed`/`provider-error`/`stalled`), turns used vs budget, repair cycles used vs budget, token totals + per-turn breakdown, and wall-clock duration; the CLI prints one final outcome line (exit path, verification, commit hash if any, duration, tokens).
- **AC-8.6 (commit failure is an outcome)** When the end-of-run git commit fails (e.g. `git add -A` exits 128 on an embedded repo), the run rolls back per the snapshot contract and ends with `exitPath: commit-failed`; `summary.md` is still written and names the git error; no unhandled stack trace reaches the user.
- **AC-8.7 (progress with tokens)** In plain mode, each turn's output is prefixed `[turn k/N · <in> in / <out> out]` with cumulative totals (compact `12.3k` formatting); tool results stay one line each.
- **AC-8.8 (interactive on a TTY)** With stdout a TTY and neither `--json` nor `--plain`: a bottom-pinned status line redraws in place (spinner while a provider call is in flight, elapsed time, turn counter vs budget, cumulative tokens); assistant text and tool results scroll above it; the final outcome line replaces it; cursor and status line are restored/cleared on exit including Ctrl-C. A renderer reused across runs (the `create` pipeline) renders every stage: each outcome line releases the status line and the next stage re-establishes it. Interactive chrome may use muted SGR color (copper accent, dim secondary text, green/amber/red for outcome); color is never required for correctness.
- **AC-8.9 (plain fallback)** With stdout piped, or `--json`, or the global `--plain` flag: output is line-oriented and contains zero ANSI escape sequences. With `--json`, progress lines go to stderr; stdout carries only the machine-readable result.
- **AC-8.10 (redaction holds)** A string matching `sk-[A-Za-z0-9_-]+` planted in any metadata field appears redacted in both the persisted `run-start` event and `summary.md` (extends AC-4.1 to the new surfaces).

### AC-16 · Deterministic schematic drafting (change: deterministic-schematic-drafting)

Placement, routing, and legibility are computed from the netlist rather than sampled from a model. The engine owns every coordinate; the model authors intent only.

**Engine — placement and routing**

- **AC-16.1 (reproducible placement)** The same IR drafted twice on machines with identical vendored symbol sources yields byte-identical `.kicad_sch` files.
- **AC-16.2 (on-grid by construction)** For any IR, every symbol origin and wire endpoint lies on the 1.27 mm grid, and the legibility checker's `off-grid` family reports zero findings.
- **AC-16.3 (drafts are legible)** A Tier C reference IR drafts to output with zero error-severity legibility findings.
- **AC-16.6 (unknown pin rejected)** An IR connecting `U1.99` when the resolved symbol has no pin 99 fails with a numbered finding naming U1, pin 99, and the symbol's actual pin range; the previous schematic is unchanged.
- **AC-16.7 (BOM mismatch rejected)** An IR part whose refdes is absent from BOM.md, or whose value differs from BOM.md's, fails validation naming the refdes and both values, before any placement runs.
- **AC-16.8 (power nets are never routed)** A power-class net reaching twelve pins draws one power symbol per reached pin and no wire spanning them.
- **AC-16.9 (undriven rail gets a PWR_FLAG)** A power-class net sourced only by a connector pin carries exactly one synthesized `PWR_FLAG`, and ERC reports no undriven-power violation.
- **AC-16.10 (declared no-connect passes ERC)** An IR declaring `U1.8` no-connect emits a `(no_connect …)` marker at that pin, and ERC reports no unconnected-pin violation for it.
- **AC-16.11 (report embeds check and score)** A successful draft's report carries the checker's findings (or a clean statement) and the score composite with its breakdown, without separate tool calls.
- **AC-16.31 (straight-through passives)** A series RC between two aligned pins, drafted within one group, puts both passives on the shared axis with zero bends in every wire of the chain.
- **AC-16.36 (series parts lie on the row)** A two-lead part whose run from an IC's side pin ends on a signal net is placed on that pin's row beside the IC, rotated so its near lead faces the pin and its far lead points away, one gap past the pin's stub; a horizontal-pinned two-lead part (diode, LED, fuse, switch) is oriented the same way, and may hang when its run ends on a rail or ground. Runs on rows one pitch apart do not overlap in x.
- **AC-16.37 (local runs are wired)** For every signal net, each cluster of endpoints within one group and within wire span of one another that routes cleanly is drawn as one wired run with one label, whatever the rest of the net does; a cluster that cannot be routed whole is drawn as its largest routable subset. A net that leaves the group therefore still wires the part on its pin.
- **AC-16.38 (nets are coloured by function)** Wires and labels of every rail net share one colour, every ground net another, and every family of signal nets sharing a prefix before the first underscore (two or more members) a colour of its own from a fixed palette in family-name order; a lone signal keeps the theme default.
- **AC-16.39 (test points rise beside their net)** A one-pin test point whose net reaches an IC's side pin within one group hangs above that pin's row beside the IC and is wired to it.
- **AC-16.35 (parts hang on the pin they serve)** A vertical two-lead part whose net reaches an IC's side pin within one group is placed on that pin's row beside the IC, below it when entered through its top lead and above it through its bottom lead, with a series chain continued through two-endpoint links; every hangable endpoint of the pin's net hangs, so the net draws as one wired net with one label. A hang the clearance check refuses is drawn in a column and reported by name in the draft notes.

**Emission — determinism and fidelity**

- **AC-16.4 (byte-identical regeneration)** Drafting the same IR, committing, and drafting again leaves `git diff` over the schematic empty.
- **AC-16.5 (library upgrade is inert)** When the installed KiCad symbol library changes after a symbol was vendored, re-drafting the same IR is byte-identical to the pre-upgrade output, and `verify_symbols` reports the divergence between vendored and installed sources.
- **AC-16.12 (output loads in kicad-cli)** Every golden IR drafted in CI loads in `kicad-cli` without error, and ERC runs to completion.
- **AC-16.13 (connectivity matches intent)** Parsing a drafted reference IR yields a net list equal to the IR's connection list, with no-connect pins excluded.

**Legibility checker**

- **AC-16.27 (clean fixture is clean)** The checker reports zero findings at every severity on the well-drafted fixture schematic.
- **AC-16.28 (checker is inert)** Running the checker leaves the schematic's bytes unchanged and makes no subprocess or network call.
- **AC-16.29 (grid findings lead)** On a sheet with both `off-grid` findings and findings from other families, the `off-grid` findings appear before every other family in the report.
- **AC-16.30 (family can be disabled)** With `legibility.severity.crowding` set to `off`, no `crowding` findings are produced and the family is listed as disabled in the report.

**Scoring and the three-tier harness**

- **AC-16.14 (scoring is reproducible)** Two scorer runs on the same schematic produce identical metrics and composite.
- **AC-16.15 (error finding caps the score)** A sheet scoring well on every metric but carrying one error-severity legibility finding reports a composite capped below the Tier A floor, with the cap stated in the breakdown.
- **AC-16.16 (Tier A catches false positives)** A checker or scorer change that raises an error-severity finding on a Tier A sheet fails CI, naming the sheet and the finding.
- **AC-16.17 (Tier B catches detection regressions)** A change that stops a Tier B fixture's pinned finding from being reported fails CI, naming the fixture and the missing finding.
- **AC-16.18 (Tier C catches engine regressions)** An engine change that alters a Tier C output's bytes or lowers its pinned score fails CI with the file diff or the score delta.
- **AC-16.32 (aesthetic metrics are measured)** The breakdown reports axis-alignment ratio, spacing uniformity, straight-wire ratio, label alignment, whitespace balance, and pair symmetry as individual metrics with their weights and contributions.
- **AC-16.33 (wiring style is measured)** The breakdown reports `pin-attachment` (share of two-pin parts with a pin wired, through endpoint and T joins, to another part's pin), `island-parts` (share of two-pin parts whose every pin ends in a label or nothing), `power-symbol-economy` (power symbols per part) and `labels-per-part` as individual metrics; a resistor wired to an IC pin scores attachment 1 and a resistor hung on two labels scores 0 with islands 1.
- **AC-16.34 (style composite is convention-free)** The report carries a wiring-style composite computed from the AC-16.33 metrics, crossings per wire and the straight-wire ratio only; it is never capped by legibility findings, so a sheet with no group rectangles and an engine draft of the same circuit compare on one scale, and `copperhead score schematic --file <sheet>` reports it for any sheet without a repo.

**Agent loop and create pipeline**

- **AC-16.19 (model authors no geometry)** When the schematic stage completes in drafting mode, every geometry element was written by the engine and the transcript holds no `edit_file` call against the schematic.
- **AC-16.20 (stale draft does not complete the stage)** When the schematic on disk does not match a re-draft of the current IR, `create` reports the stage contract as unmet with a resume hint to re-draft, and does not advance.
- **AC-16.21 (score is recorded)** A schematic stage completing with an engine-drafted sheet records the score composite and per-metric breakdown in the run summary.
- **AC-16.22 (illegible sheet does not complete the stage)** When the stage's run succeeds with symbols present and drift clean but the checker reports error-severity legibility findings, `create` reports the contract as unmet with finding counts by kind, does not advance, and a re-run resumes at the schematic stage.
- **AC-16.23 (hand edit is redirected to the IR)** An `edit_file` call against an engine-drafted schematic during the schematic stage is refused naming `draft_schematic` as the correct path, and no file changes.
- **AC-16.24 (`finish` refuses while illegible)** Calling `finish` with outcome "done" while error-severity legibility findings remain lists them as unmet obligations, and the run does not conclude as done.

**CLI surface — legibility never gates `check`**

- **AC-16.25 (illegible schematic still exits zero)** `check` on a repo with error-severity legibility findings but clean ERC and DRC prints them under a legibility heading and exits 0.
- **AC-16.26 (score rides along without gating)** `check --json` on a repo with a drafted schematic and a low composite carries the `score` object with composite and breakdown, and the exit code is unaffected.

### AC-5 · Viewer (Phase 2 — only if built)

- **AC-5.1** `copperhead watch` serves on localhost; page shows current schematic SVG within 2 s of load.
- **AC-5.2** During a `do` run, the SVG re-renders without manual refresh after each file mutation; ERC/DRC status chip updates red→green.
- **AC-5.3** Before/after toggle flips between pre-run and current render.
- **AC-5.4** Agent plan/edit/verify turns stream into the left pane as they happen.

### AC-6 · Submission readiness (hard gate, 5:30 PM)

- **AC-6.1** Repo is public; README quickstart works on a clean machine (fresh clone, `npm i -g .` or `npx`, kicad-cli present) — actually tested, not assumed.
- **AC-6.2** One full recorded run (screen capture) exists locally — the demo fallback.
- **AC-6.3** 1-minute video exported and uploaded.
- **AC-6.4** At least AC-3.1, AC-3.2, and AC-3.4 pass live on the demo machine — these three are the pitch.

**Priority if time runs out:** AC-3.4 > AC-3.2 > AC-3.1 > AC-2.1 > AC-1.2 > everything else. The budget-refusal demo (AC-3.4) is the single strongest proof that this is reasoning, not autocomplete.

## 10. Non-goals (hackathon day)

- No autorouting, no placement optimization
- No full s-expression round-trip library (parse for *reading* lists/nets only; *edits* are anchored text replaces)
- No auth, no hosting, no billing
- No Altium/Eagle formats
- No Windows support guarantees (macOS/Linux only today)

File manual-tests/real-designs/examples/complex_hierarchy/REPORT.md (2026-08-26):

# complex_hierarchy

Source: `/usr/share/kicad/demos/complex_hierarchy/complex_hierarchy.kicad_sch`
Parts: 68  Nets: 50

## Drafted

Paper: A1  Wires: 176  Labels: 118

## Netlist comparison

Pin groups lost: **0**  gained: **0**

The drafted sheet joins exactly the same pins as the source. The two
drawings differ in layout, which is expected and not a defect.

## Side by side

Original (drawn by a person):

- `render/original-complex_hierarchy-ampli_ht_horizontal.png`
- `render/original-complex_hierarchy-ampli_ht_vertical.png`
- `render/original-complex_hierarchy.png`

Drawn by the engine:

- `render/drawn.png`

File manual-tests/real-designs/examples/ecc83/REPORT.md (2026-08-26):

# ecc83

Source: `/usr/share/kicad/demos/ecc83/ecc83-pp.kicad_sch`
Parts: 15  Nets: 9

## Drafted

Paper: A3  Wires: 29  Labels: 29

## Netlist comparison

Pin groups lost: **0**  gained: **0**

The drafted sheet joins exactly the same pins as the source. The two
drawings differ in layout, which is expected and not a defect.

## Side by side

Original (drawn by a person):

- `render/original.png`

Drawn by the engine:

- `render/drawn.png`

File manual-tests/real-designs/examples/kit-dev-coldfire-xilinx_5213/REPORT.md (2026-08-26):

# kit-dev-coldfire-xilinx_5213

Source: `/usr/share/kicad/demos/kit-dev-coldfire-xilinx_5213/kit-dev-coldfire-xilinx_5213.kicad_sch`
Parts: 160  Nets: 209

## Drafted

Paper: A0  Wires: 769  Labels: 491

## Netlist comparison

Pin groups lost: **0**  gained: **0**

The drafted sheet joins exactly the same pins as the source. The two
drawings differ in layout, which is expected and not a defect.

## Side by side

Original (drawn by a person):

- `render/original-kit-dev-coldfire-xilinx_5213-inout_user.png`
- `render/original-kit-dev-coldfire-xilinx_5213-xilinx.png`
- `render/original-kit-dev-coldfire-xilinx_5213.png`

Drawn by the engine:

- `render/drawn.png`

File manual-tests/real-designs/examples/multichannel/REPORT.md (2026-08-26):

# multichannel

Source: `/usr/share/kicad/demos/multichannel/multichannel_mixer.kicad_sch`
Parts: 114  Nets: 79

## Drafted

Paper: A1  Wires: 303  Labels: 234

## Netlist comparison

Pin groups lost: **0**  gained: **0**

The drafted sheet joins exactly the same pins as the source. The two
drawings differ in layout, which is expected and not a defect.

## Side by side

Original (drawn by a person):

- `render/original-multichannel_mixer-CH1.png`
- `render/original-multichannel_mixer-CH2.png`
- `render/original-multichannel_mixer-CH3.png`
- `render/original-multichannel_mixer-CH4.png`
- `render/original-multichannel_mixer.png`

Drawn by the engine:

- `render/drawn.png`

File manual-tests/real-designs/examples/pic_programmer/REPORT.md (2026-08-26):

# pic_programmer

Source: `/usr/share/kicad/demos/pic_programmer/pic_programmer.kicad_sch`
Parts: 63  Nets: 34

## Drafted

Paper: A0  Wires: 182  Labels: 88

## Netlist comparison

Pin groups lost: **0**  gained: **0**

The drafted sheet joins exactly the same pins as the source. The two
drawings differ in layout, which is expected and not a defect.

## Side by side

Original (drawn by a person):

- `render/original-pic_programmer-pic_sockets.png`
- `render/original-pic_programmer.png`

Drawn by the engine:

- `render/drawn.png`

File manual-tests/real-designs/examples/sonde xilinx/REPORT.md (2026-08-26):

# sonde xilinx

Source: `/usr/share/kicad/demos/sonde xilinx/sonde xilinx.kicad_sch`
Parts: 25  Nets: 26

## Drafted

Paper: A2  Wires: 112  Labels: 58

## Netlist comparison

Pin groups lost: **0**  gained: **0**

The drafted sheet joins exactly the same pins as the source. The two
drawings differ in layout, which is expected and not a defect.

## Side by side

Original (drawn by a person):

- `render/original.png`

Drawn by the engine:

- `render/drawn.png`

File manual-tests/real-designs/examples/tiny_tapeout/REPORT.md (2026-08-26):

# tiny_tapeout

Source: `/usr/share/kicad/demos/tiny_tapeout/tinytapeout-demo.kicad_sch`
Parts: 150  Nets: 108

## Drafted

Paper: A0  Wires: 582  Labels: 310

## Netlist comparison

Pin groups lost: **0**  gained: **0**

The drafted sheet joins exactly the same pins as the source. The two
drawings differ in layout, which is expected and not a defect.

## Side by side

Original (drawn by a person):

- `render/original-tinytapeout-demo.png` (rendered separately: the sheet embeds a bitmap logo that ImageMagick reports as an error while still painting everything else, so the sweep marked it unrendered)
- `render/original-tinytapeout-demo-RP2040.png`

Drawn by the engine:

- `render/drawn.png`

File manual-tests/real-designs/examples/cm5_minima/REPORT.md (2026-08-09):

# cm5_minima

Source: `/usr/share/kicad/demos/cm5_minima/CM5_MINIMA_3.kicad_sch`
Parts: 84  Nets: 95

## Drafted

Paper: A0  Wires: 478  Labels: 204

## Netlist comparison

Pin groups lost: **0**  gained: **0**

The drafted sheet joins exactly the same pins as the source. The two
drawings differ in layout, which is expected and not a defect.

## Side by side

Original (drawn by a person):

- `manual-tests/runs/real-designs/cm5_minima/render/original-CM5_MINIMA_3-CM5.png`
- `manual-tests/runs/real-designs/cm5_minima/render/original-CM5_MINIMA_3-DSI_CSI.png`
- `manual-tests/runs/real-designs/cm5_minima/render/original-CM5_MINIMA_3-Ethernet.png`
- `manual-tests/runs/real-designs/cm5_minima/render/original-CM5_MINIMA_3-HDMI.png`
- `manual-tests/runs/real-designs/cm5_minima/render/original-CM5_MINIMA_3-IO.png`
- `manual-tests/runs/real-designs/cm5_minima/render/original-CM5_MINIMA_3-PCIe-M2.png`
- `manual-tests/runs/real-designs/cm5_minima/render/original-CM5_MINIMA_3-USB.png`
- `manual-tests/runs/real-designs/cm5_minima/render/original-CM5_MINIMA_3.png`

Drawn by the engine:

- (not rendered)

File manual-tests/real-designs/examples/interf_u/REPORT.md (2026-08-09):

# interf_u

Source: `/usr/share/kicad/demos/interf_u/interf_u.kicad_sch`
Parts: 24  Nets: 110

## Drafted

Paper: A3  Wires: 329  Labels: 240

## Netlist comparison

Pin groups lost: **0**  gained: **0**

The drafted sheet joins exactly the same pins as the source. The two
drawings differ in layout, which is expected and not a defect.

## Side by side

Original (drawn by a person):

- (not rendered)

Drawn by the engine:

- `manual-tests/runs/real-designs/interf_u/render/drawn.png`

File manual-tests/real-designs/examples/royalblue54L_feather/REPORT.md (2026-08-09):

# royalblue54L_feather

Source: `/usr/share/kicad/demos/royalblue54L_feather/RoyalBlue54L-Feather.kicad_sch`
Parts: 71  Nets: 68

## Drafted

Paper: A1  Wires: 292  Labels: 150

## Netlist comparison

Pin groups lost: **0**  gained: **0**

The drafted sheet joins exactly the same pins as the source. The two
drawings differ in layout, which is expected and not a defect.

## Side by side

Original (drawn by a person):

- `manual-tests/runs/real-designs/royalblue54L_feather/render/original-RoyalBlue54L-Feather-Connectors.png`
- `manual-tests/runs/real-designs/royalblue54L_feather/render/original-RoyalBlue54L-Feather-Debugger.png`
- `manual-tests/runs/real-designs/royalblue54L_feather/render/original-RoyalBlue54L-Feather-nPM1300.png`
- `manual-tests/runs/real-designs/royalblue54L_feather/render/original-RoyalBlue54L-Feather-nRF54L15.png`
- `manual-tests/runs/real-designs/royalblue54L_feather/render/original-RoyalBlue54L-Feather.png`

Drawn by the engine:

- `manual-tests/runs/real-designs/royalblue54L_feather/render/drawn.png`

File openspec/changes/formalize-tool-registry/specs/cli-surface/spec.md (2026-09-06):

# cli-surface — Delta Spec

## ADDED Requirements

### Requirement: `skill` command
The CLI SHALL provide `copperhead skill list` and `copperhead skill run <name>`. `skill list` SHALL print registered skills and whether each would be present in `registry.list(ctx)` for the current repo, make zero LLM calls, make zero network calls, and create no transcript or run directory. `skill run <name>` SHALL invoke that skill's nested sub-run with the same definition the model catalog uses and print the resulting envelope. A missing API key on `skill run` SHALL exit non-zero with a message naming the missing env var and without a stack trace. An unknown skill name SHALL exit non-zero naming the name. `skill run` SHALL close the provider it created before the process exits, on the success, failure, and throw paths alike, so no saved-login working directory or subprocess outlives the command.

#### Scenario: Help lists skill
- **WHEN** `copperhead --help` is run
- **THEN** the output lists `skill` with a one-line description

#### Scenario: list is LLM-free
- **WHEN** `copperhead skill list` runs on the fixture repo with no API keys in the environment
- **THEN** it exits 0, prints `generate_report`, makes no network calls to any api.* host, and does not create `.copperhead/runs/`

#### Scenario: run generate-report
- **WHEN** `copperhead skill run generate-report` completes with a provider available
- **THEN** stdout contains the report summary and ERC/DRC/drift results, and no new repo file was created solely to hold that report

#### Scenario: run without a key fails clearly
- **WHEN** `copperhead skill run generate-report` is invoked with no model API key and no saved-login provider configured
- **THEN** the process exits non-zero, names the missing env var or login, and prints no stack trace

#### Scenario: unknown skill
- **WHEN** `copperhead skill run does-not-exist` is invoked
- **THEN** the process exits non-zero and the message contains `does-not-exist`

#### Scenario: run releases its provider
- **WHEN** `copperhead skill run <name>` finishes, whether the report succeeded, the provider threw, or the skill name was unknown
- **THEN** the provider it created has been closed before the process exits, and a provider whose `close` itself throws yields a warning rather than losing the run result

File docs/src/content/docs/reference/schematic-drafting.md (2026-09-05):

---
title: How schematics are drafted
description: The deterministic drafting engine, the rules it follows, and how a netlist intent becomes a placed, wired, readable sheet.
sidebar:
  order: 4
---

:::note
Specified by the `deterministic-schematic-drafting` OpenSpec change. This page explains the inner workings; the rules the finished sheet must satisfy are defined in [Schematic legibility rules](/reference/schematic-legibility/).
:::

copperhead does not ask the model to draw. During `create`'s schematic stage the model authors an *intent*: which parts exist, which pins connect, and which subsystem each part belongs to. A deterministic engine then computes every coordinate, wire, and label on the sheet. The same intent always produces the same sheet, byte for byte, on any machine.

This split exists for three reasons. Placement chosen token by token drifts from run to run and reads like it. The geometry text is where the token cost and the mid-turn failures concentrate. And a rule engine can be held to a standard mechanically: the legibility checker and the score run against its output on every change, so drawing quality is a regression test, not a hope.

## The pipeline

```text
schematic.intent.json          (model writes this: parts, nets, groups, hints)
        |
   validate      unknown symbol, missing pin, ungrouped part: stop here,
        |        numbered findings, nothing written
   reduce        power rails and ground become per-pin symbols;
        |        decoupling caps row up beside their IC;
        |        connectors go to the sheet edges
   lay out       subsystem groups tile left to right along signal flow,
        |        each sized from the symbols it must hold
   place         inside each group: columns by signal depth,
        |        ordered to keep connected pins near each other,
        |        every coordinate an integer grid step
   wire          short local connections get real wires;
        |        everything else gets a net label
   emit          canonical .kicad_sch text, stable UUIDs,
        |        library symbols copied verbatim
        v
   .kicad_sch    then: ERC, the legibility checker, and the score
```

## The intent file

`schematic.intent.json`, versioned, living beside the schematic:

```json
{
  "version": 1,
  "parts": [
    { "ref": "U1", "libId": "CopperMCU:MCU8", "value": "MCU8",
      "footprint": "Package_SO:SOIC-8_3.9x4.9mm_P1.27mm", "group": "MCU" }
  ],
  "nets": [
    { "name": "VCC", "pins": ["J1.1", "U1.1", "C1.1"] },
    { "name": "DIV", "pins": ["R1.2", "R2.1", "U1.3"], "kind": "signal" }
  ],
  "noConnect": ["U1.4", "U1.5"],
  "hints": { "groupOrder": ["Power", "MCU"], "paper": "A4", "date": "2026-07-31" }
}
```

Every part names its subsystem group (a SUBSYSTEMS.md heading) and is cross-checked against BOM.md at validation, so a transcription slip dies before anything is drawn. `kind` overrides the automatic power-net recognition when the inference is wrong; the draft report always lists every net's resolved class. `hints.date` fills the title block: it belongs to the intent, not the wall clock, so the same intent emits the same bytes on any day. The full field-by-field specification, including every validation rule and refusal, is on [The schematic intent file](/reference/schematic-intent/).

## What the model controls, and what it cannot

The intent file (`schematic.intent.json`) carries parts (library id, refdes, value), connections (net name to a list of `refdes.pin` endpoints), one subsystem group per part taken from SUBSYSTEMS.md, and optional hints: port direction, group ordering, paper size. It contains no coordinates, and the engine ignores none of its rules in favor of a hint.

When a gate objects (ERC, a legibility finding, a low score), the fix is a revised intent and a re-draft. The agent's file-editing tools refuse to touch an engine-drafted schematic, because a hand edit would be destroyed by the next re-draft. Hand-drawn schematics in existing repos are never touched by the engine; `copperhead do` edits them exactly as before.

## The drafting rules

The engine follows the conventions a careful human drafter uses, applied in a fixed order.

**Power is never routed.** A net is classified as a rail or ground by a deterministic rule (it touches a pin whose library type is power-in or power-out, or the intent declares it; the declaration wins, and the draft report lists every net's resolved class). Classified nets are removed from the wiring problem before layout: every pin they reached gets its own power-port symbol, rails pointing up, grounds pointing down, at uniform heights. A twelve-pin ground net becomes twelve small ground symbols, not a wire tree across the sheet. A rail with no power-output driver gets one synthesized `PWR_FLAG`, and pins the intent declares unconnected get `no_connect` markers, so ERC passes on drafted output without hand intervention.

**Decoupling capacitors stay with their IC.** A two-pin capacitor between a rail and ground is classified as decoupling and placed in a row beside the IC that shares its nets, with a rail label, the way a reviewer expects to find it.

**Connectors sit at the edges.** Parts classified as connectors are assigned to the left or right sheet edge, matching the direction hint if one is given (inputs left, outputs right).

**Groups tile the sheet.** Each subsystem from SUBSYSTEMS.md becomes one captioned box. Groups are ordered left to right along signal flow (sources toward the left, loads toward the right) and sized from the summed body boxes of their symbols plus clearance, so the sheet fills the frame instead of crowding one corner.

**Placement inside a group is layered.** Symbols are assigned to columns by their depth in the signal chain (longest-path layering), then ordered within each column to sit near the symbols they connect to (barycenter ordering). All arithmetic happens in integer multiples of the 1.27mm grid, so every pin lands on-grid by construction rather than by rounding.

**Wires are local or they are labels.** A real wire is drawn only for a net that stays inside one group, touches at most four pins, and fits a distance budget: a voltage divider's tap or a crystal with its load caps gets drawn wires with junction dots, the way a person would draw it. Wires run only inside channels reserved between placement columns, so they can never cross a symbol body. Every other connection, including everything that crosses a group boundary, becomes a matched pair of net labels, horizontal wherever a horizontal label fits. This is how dense professional schematics are drawn, and it is why the engine does not need a general-purpose autorouter.

**Text never fights the drawing.** Reference and value text slots are computed with the symbol placement, so labels cannot land on a neighbour's body or wire.

**The sheet is aligned and balanced, not merely legal.** Column placement provides the baseline (shared column axes, uniform sibling spacing in decoupling rows, centered groups, a balanced page), and two idiom passes then redraw the small structures a human drafts by reflex. A maximal run of two-lead vertical parts linked by two-endpoint nets (a pull-up on its pin, a series RC to ground, a divider between rails) is restacked as one straight vertical line on its anchor pin's stub axis, uniform gaps, rail or ground symbol at the free end, so its wires run dead straight; a crystal's load capacitors drop below the crystal's own pins, which places them mirror-symmetric at equal offsets by construction. Both passes are strictly conservative: a move is refused outright if any body, any visible text slot, the growth of a power symbol, or any foreign pin or stub end on the run's axis would be disturbed, because a chain routed down a column of neighbouring stub ends would silently merge nets, which is worse than a less pretty column. Symmetry and alignment stay computed properties, and the score measures them (axis alignment, spacing uniformity, straight-wire ratio, whitespace balance, pair symmetry) so an update that makes sheets uglier fails its benchmark even when every hard rule still passes.

**The title block is filled** from the project configuration: title, revision, date.

## Determinism

Determinism is structural, not best-effort. The engine uses no randomness, no clock, and no environment-dependent ordering. Every UUID in the emitted file is derived (UUIDv5) from a stable semantic path such as `sheet/U1/pin/7`, elements are emitted in a canonical order, and library symbol definitions are copied byte-for-byte from `.kicad_sym` sources vendored into the project on first use, so upgrading KiCad's libraries cannot silently change your sheet (`verify_symbols` still tells you when the installed library has moved on). Re-drafting an unchanged intent therefore produces a byte-identical file and an empty git diff; changing one net touches only the elements that net affects. One caveat: the guarantee holds for sheets copperhead owns end to end. Once a sheet is re-saved by hand in KiCad, KiCad rewrites formatting and identifiers.

## How quality is kept honest

Three instruments run against every drafted sheet, and none of them is the engine grading its own homework:

- **ERC** (via `kicad-cli`) checks the electrical facts, as it always has.
- **The legibility checker** evaluates the [thirteen check families](/reference/schematic-legibility/) read-only. Error-severity findings block the schematic stage from completing.
- **The score** (`copperhead score schematic`) measures the judgment calls: wire crossings and bends, total wire length, alignment, page utilization, label-to-wire ratio, group cohesion, and flow direction, combined into a weighted 0-100 composite whose per-metric breakdown is always printed. Any error-severity finding caps the composite, so a good number can never hide a real defect.

Behind these sits a golden corpus in CI: known-good hand-drawn sheets that must stay finding-free and above a score floor (catching checker false positives), known-bad sheets that must keep producing their exact findings (catching detection regressions), and reference intents whose drafted output is pinned byte-for-byte with its score (catching engine regressions). Goldens change only through an explicit update flag, and the resulting diff is reviewed like any other code change.

## Trying it

```bash
copperhead draft schematic   # intent in, schematic out; deterministic, offline
copperhead score schematic   # score JSON for the configured schematic
copperhead check   # ERC plus legibility findings and score, advisory, exit code unchanged
```

All three are LLM-free and network-free, safe for CI and pre-commit hooks.

## Pin-anchored hangs

A drafter puts a part on the pin it serves: the compensation network hangs off COMP, the bootstrap capacitor sits on BOOT, a pull-up rises from the pin it pulls. Before any column is packed, the engine reads each IC's side pins in order and claims the chain of vertical two-lead parts a pin's net leads into as a **hang**: entered through the part's top lead it drops below the pin's row, through its bottom lead it rises above it, and it runs on through two-endpoint links until it reaches a rail, a ground, a tapped node or a part that cannot hang. Every hangable endpoint of the pin's net hangs, each as its own chain, so a series RC and a shunt C on one pin both sit at that pin and the net stays within wire span.

A hang whose rows are free of every other connected signal pin on that side stays dead straight on the stub axis (the wire from the pin continues into the chain with no bend); otherwise it takes the first shelf slot beside the IC whose rows are free, past the IC's own labels. Slots are dealt from the lowest pin upward for hangs that drop and from the highest pin downward for hangs that rise, so a chain that passes other pins' rows is always the outer one and no branch crosses a sibling. The IC's cell reserves the shelf, so the columns start past it, and the box encloses everything.

Each hang goes through the same clearance check every idiom uses, with the chain's own connection points taken from the nets that run along its axis only, never the rail at its far end. A hang the check refuses is drawn in a column at the group's right edge and named in the draft report's notes as `hang refused: …`, so a labelled part is never a silent fallback. Crystal load capacitors are left to the crystal-flanking idiom, and decoupling capacitors stay in their bank.

Measured with the wiring-style score (see the legibility page): on the reference boards the share of two-pin parts wired straight to another part rose from 0.26 to 0.48 on buck-12v-5v and from 0.53 to 0.59 on usb-atmega-node; on a 141-part amplifier board from 0.49 to 0.57, and on the five-part Tier C golden from 0.00 to 0.67. What remains unattached is horizontal-pinned parts (diodes, LEDs, fuses, two-pin connectors, switches), which need symbol rotation, and parts whose net leaves the group.

## Series parts on the row, and rotation

A part whose run from the IC pin ends on a signal net rather than a rail or ground is a **series element** — a 100 Ω in an I2S line, an output inductor, a bootstrap capacitor between two pins of the same IC — and lies along the pin's row, away from the IC, the way a drafter draws it. The engine turns the symbol for that: a resistor from the library is vertical and lies down at 90 or 270 degrees so its near lead faces the IC, while a diode, LED, fuse or switch is horizontal already and turns only to face the right way. The same orientation rule lets those horizontal parts hang like a resistor when their run ends on a rail or ground. Each part sits one gap past the previous connection point, and the gap is at least the width of the wired net's name, so the name stands above the wire in the space left for it. Runs on rows one pitch apart start past each other's end, because two horizontal parts cannot share an x range on neighbouring rows. A run that cannot be laid on its row is drawn in a column and reported as `inline refused: …`.

## Local runs are wired

The wire pass no longer decides a net whole. Its endpoints are clustered by group and wire span, and every cluster that routes cleanly is drawn as one wired run with one label, whatever the rest of the net does; a cluster that will not route whole is drawn as its largest routable subset, and only the endpoints left over keep a stub and a label. So a part hung on a pin or lying on its row is wired to it even when the net also leaves the group or carries more endpoints than one run may hold. A run's name goes at the top of its trunk, or at the left end of a horizontal run, wherever it clears every body.

## Conventions the sheet follows

The target the engine draws toward, collected from practitioner guides, a hand-drawn reference board and the KiStack schematic skill's checklist, re-expressed here. Where a rule is the engine's, it is enforced by construction and gated; where it is the intent's, the stage prompt asks for it.

| Convention | Whose | How |
| --- | --- | --- |
| Signals flow left to right; the IC leads its group; connectors on the left | engine | IC-first layering, connector column |
| A part sits on the pin it serves: shunts hang, series parts lie on the row, test points rise beside their net | engine | pin-anchored hangs, inline runs, test-point hangs |
| Wire what is local, label what is not; one label per wired run | engine | cluster-first routing |
| Rails and grounds are symbols, rails up and grounds down, one per bank of caps | engine | power pass, bank trunks |
| Decoupling in banks with shared symbols; a PWR_FLAG at each undriven rail's first endpoint | engine | bank idiom, flag synthesis |
| Every part carries a reference and a value that collide with nothing; all text horizontal | engine | field slot ladder, text gates |
| Related nets coloured together: rails, grounds, and every family of signals sharing a prefix; lone signals in the theme default | engine | wire and label colour |
| Subsystems as captioned boxes that enclose their own text; page sized to content; boxes compact | engine | group rects, enclosure, compaction |
| Bus and interface nets share a prefix; differential pairs end in +/- or P/N; values carry units | intent | stage prompt |
| Notes, datasheet references and design intent on the sheet | not yet | needs a notes field in the intent |

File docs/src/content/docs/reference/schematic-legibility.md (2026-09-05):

---
title: Schematic legibility rules
description: The drafting standard for generated schematics and the deterministic checks that enforce it.
sidebar:
  order: 3
---

:::note
Specified by the `deterministic-schematic-drafting` OpenSpec change. This page describes the contract; the checker and the gate land with that change's implementation. How generated sheets come to satisfy these rules by construction is described in [How copperhead drafts schematics](/reference/schematic-drafting/).
:::

ERC verifies the net graph, and `verify_symbols` verifies the parts, but neither says anything about how the drawing reads. The schematic is the primary human review surface for everything the agent designs, so legibility is checked the same way: a deterministic, read-only checker (`check_legibility`) that reports findings the agent must reconcile before the schematic stage of `create` can complete.

## The drafting standard

Generated sheets follow these rules. The agent is told them up front, and the checker verifies the ones with a mechanical answer.

- **Subsystem group boxes.** Every non-power symbol belongs to exactly one drawn group: a `(rectangle)` outline with a `(text)` caption inside its top band naming the subsystem. Solid stroke for functional blocks, dashed for annotation clusters (a decoupling bank, a boot/reset cluster, spare gates). Captions must name a subsystem from SUBSYSTEMS.md or a component group from BOM.md. Power ports (`power:` symbols and `PWR_FLAG`) are exempt from membership.
- **Block-partitioned layout.** Groups tile the sheet in columns without overlapping. A large MCU or connector gets its own full-height column. Signal flow runs left to right inside a group, power rails toward the top, grounds toward the bottom.
- **Labels between blocks, wires within them.** Wires stay short and local inside a group. Connections between groups use net labels, not long wires crossing the sheet.
- **Page sized to content.** The paper size is chosen so the groups fill the frame instead of crowding one corner or spilling off the edge.
- **Title block filled.** Title, revision, and date are populated.
- **Nets coloured by function.** Rails one colour, grounds another, and every family of signals sharing a prefix (I2S_, SPI_, BTN_) a colour of its own; a lone signal keeps the default. The colour is on the wires and the labels, so a bus reads as one thing across the sheet.
- **Everything on grid.** Symbol origins, wire endpoints, and label positions sit on the 1.27mm grid. An off-grid pin silently fails to connect, so grid findings are always reported first.

## Check families

Each finding carries a stable kind identifier. Error-severity families gate the `create` schematic stage; advisory families inform but never block.

| Kind | Severity | Detects |
| --- | --- | --- |
| `off-grid` | error | A symbol origin, wire endpoint, or label position off the 1.27mm grid. Reported first. |
| `symbol-overlap` | error | Two symbol body boxes intersecting. |
| `text-collision` | error | Reference, Value, label, or free text over a symbol body, a wire, or other text. |
| `wire-through-symbol` | error | A wire crossing a symbol body without terminating on one of its pins. |
| `out-of-frame` | error | Content outside the usable frame area or over the title block. |
| `ungrouped-symbol` | error | A non-power symbol inside no group rectangle. |
| `unlabeled-group` | error | A group with no caption, or a caption naming nothing in SUBSYSTEMS.md or BOM.md. |
| `group-overlap` | error | Two group rectangles intersecting without one fully containing the other. |
| `empty-title-block` | error | An empty title, revision, or date field. |
| `label-orientation` | advisory | A label rotated 90 or 270 degrees where a horizontal draw would collide with nothing. |
| `low-utilization` | advisory | Content occupying less than the configured fraction of the usable frame area. |
| `crowding` | advisory | Neighbouring symbols closer than the minimum readable pitch. |
| `cross-group-wire` | advisory | A wire crossing a group boundary, or exceeding the maximum length, where a label pair belongs. |

The split is deliberate: every gating family has an unambiguous answer and a single resolving move, while the advisory families rest on thresholds, and gating on a threshold invites the repair loop to thrash against a number instead of fixing a defect.

A horizontal label is measured standing on its anchor, one text height above the wire it names and nothing below it, the way eeschema draws it; a label on a horizontal wire is therefore not text on a wire. What the checker deliberately excludes: pin name and pin number text participate in no collision test (they sit inside IC outlines by design), a label never collides with the wire it is attached to, and text extents are estimated at a fixed 0.6 × font height per character, below the stroke font's average advance, so the checker misses marginal collisions rather than inventing them.

## Where the checks bind

- **`copperhead create` gates.** The schematic stage completes only when the sheet has symbols, BOM/PINOUT are drift-clean, ERC passes, and zero error-severity legibility findings remain. Error findings also feed the sync-obligations ledger, so `finish` refuses while any are outstanding. Editing the schematic re-opens the obligation; a clean `check_legibility` run clears it. The ledger obligation binds only on repos copperhead created: a `do` run on a hand-drawn schematic gets the same findings as information, never as a block, since a pre-existing sheet should not have to be redrawn to accept a one-line edit.
- **`copperhead check` reports.** Findings print grouped by severity, and the exit code is unaffected at every severity: hand-drawn schematics in existing repos gain information, not a new failure class. `check --json` carries a `legibility` object with the findings, per-severity counts, and any skipped or disabled families. The key is always present, even when clean or when no schematic is configured.
- **Loud skips, never silent.** An unrecognized `(paper)` size skips the page-relative checks with a stated reason. A missing SUBSYSTEMS.md or BOM.md skips caption validation the same way, while the geometric group checks still run.

## Configuration

Optional `legibility` block in `.copperhead/config.json`. Absent keys use these defaults:

| Key | Default | Meaning |
| --- | --- | --- |
| `thresholds.gridPitch` | `1.27` | Grid pitch in mm for the `off-grid` family. |
| `thresholds.minPitch` | `2.54` | Minimum readable symbol pitch, edge to edge between body boxes, in mm. |
| `thresholds.utilization` | `0.5` | Minimum fraction of the usable frame area content should occupy. |
| `thresholds.maxWireLength` | `50.8` | Wire length in mm beyond which a label pair is suggested. |
| `thresholds.familyCap` | `10` | Maximum findings per family per sheet; the remainder is reported as a suppressed count. |
| `severity.<kind>` | per table above | Override any family to `error`, `advisory`, or `off`. `off` disables the family and the report says so. |

Geometric comparisons apply a 0.01mm tolerance so file-precision noise cannot flip a finding.
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

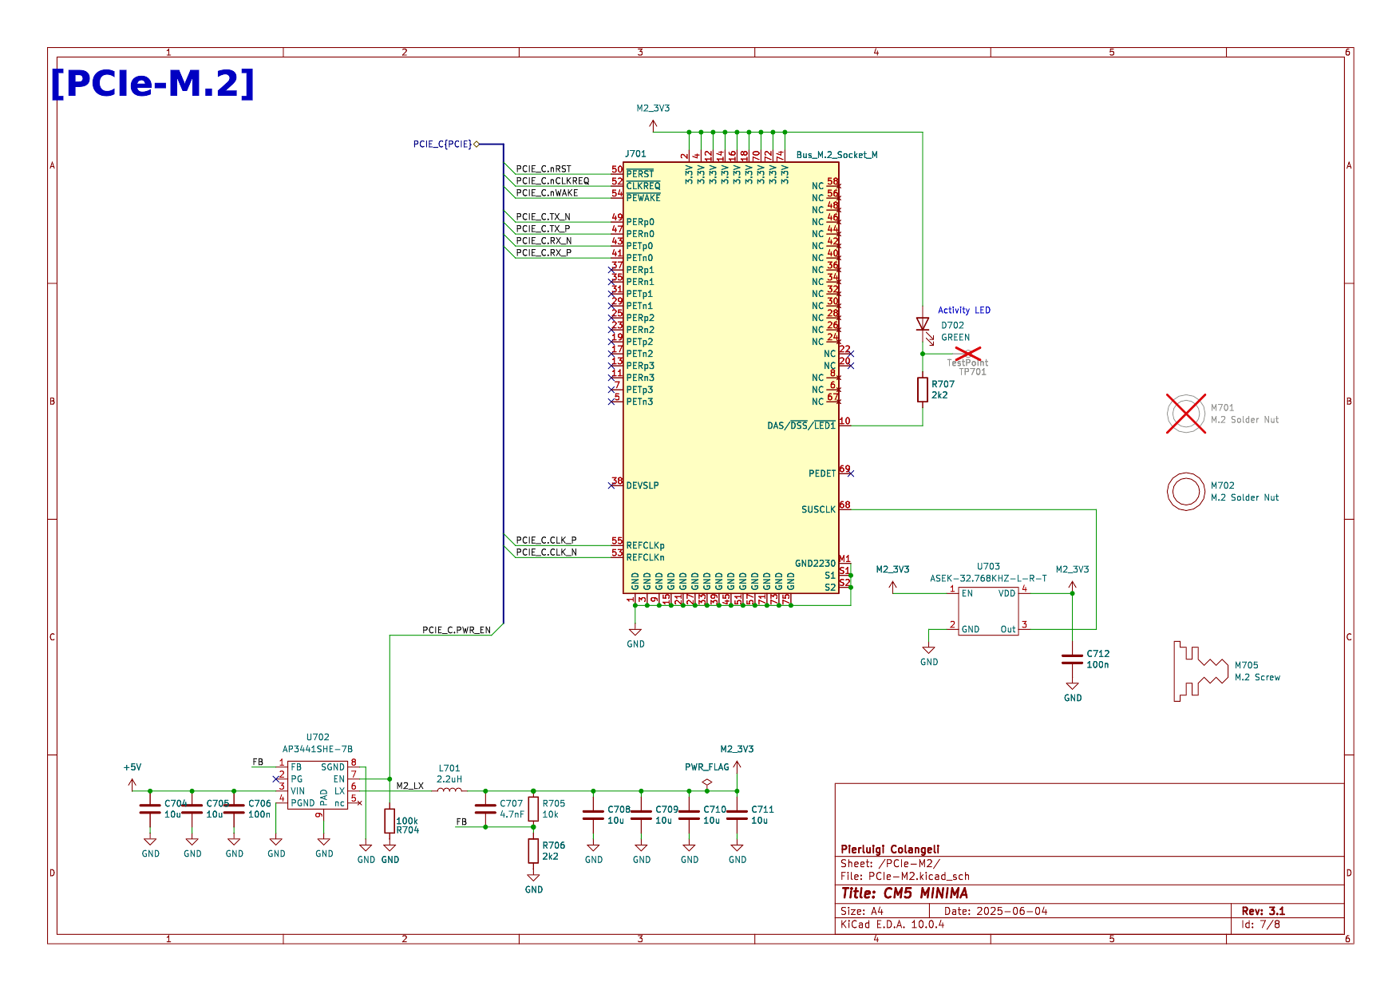
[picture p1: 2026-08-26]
manual-tests/real-designs/examples/cm5_minima/render/original-CM5_MINIMA_3-PCIe-M2.png

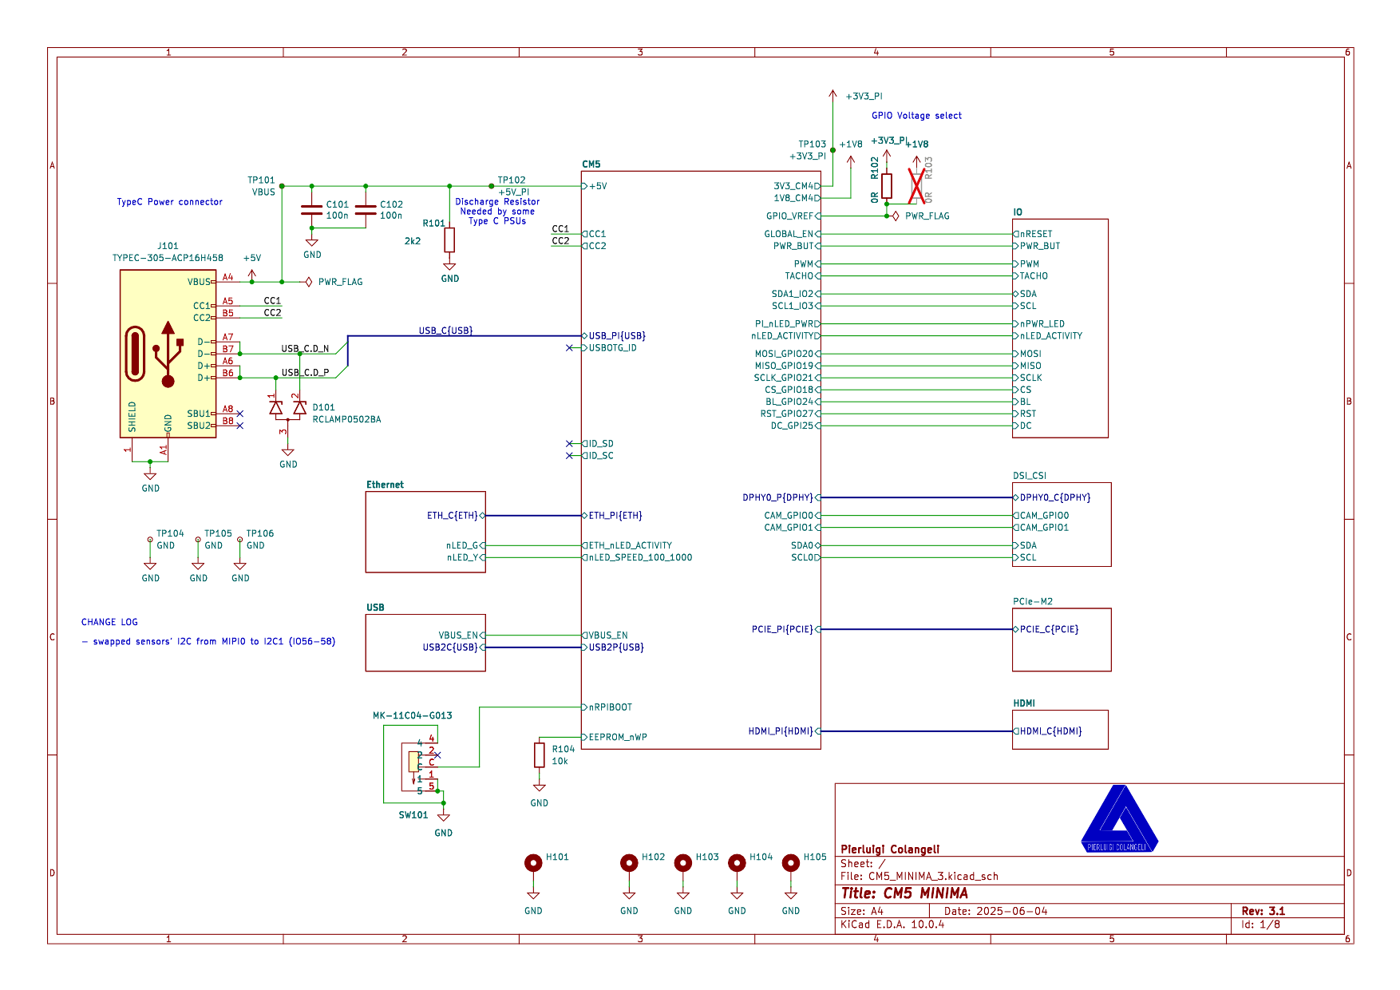
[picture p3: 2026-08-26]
manual-tests/real-designs/examples/cm5_minima/render/original-CM5_MINIMA_3.png

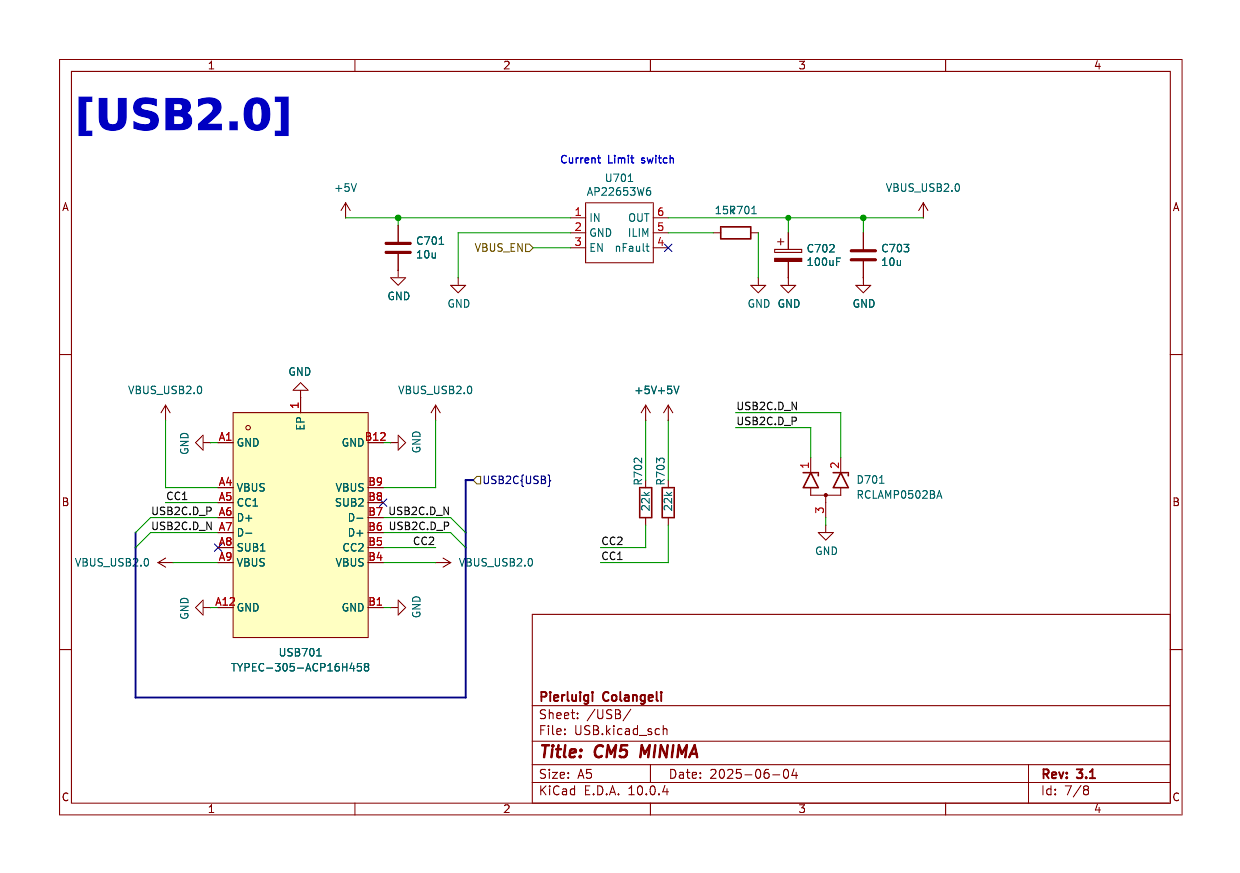
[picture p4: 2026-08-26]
manual-tests/real-designs/examples/cm5_minima/render/original-CM5_MINIMA_3-USB.png

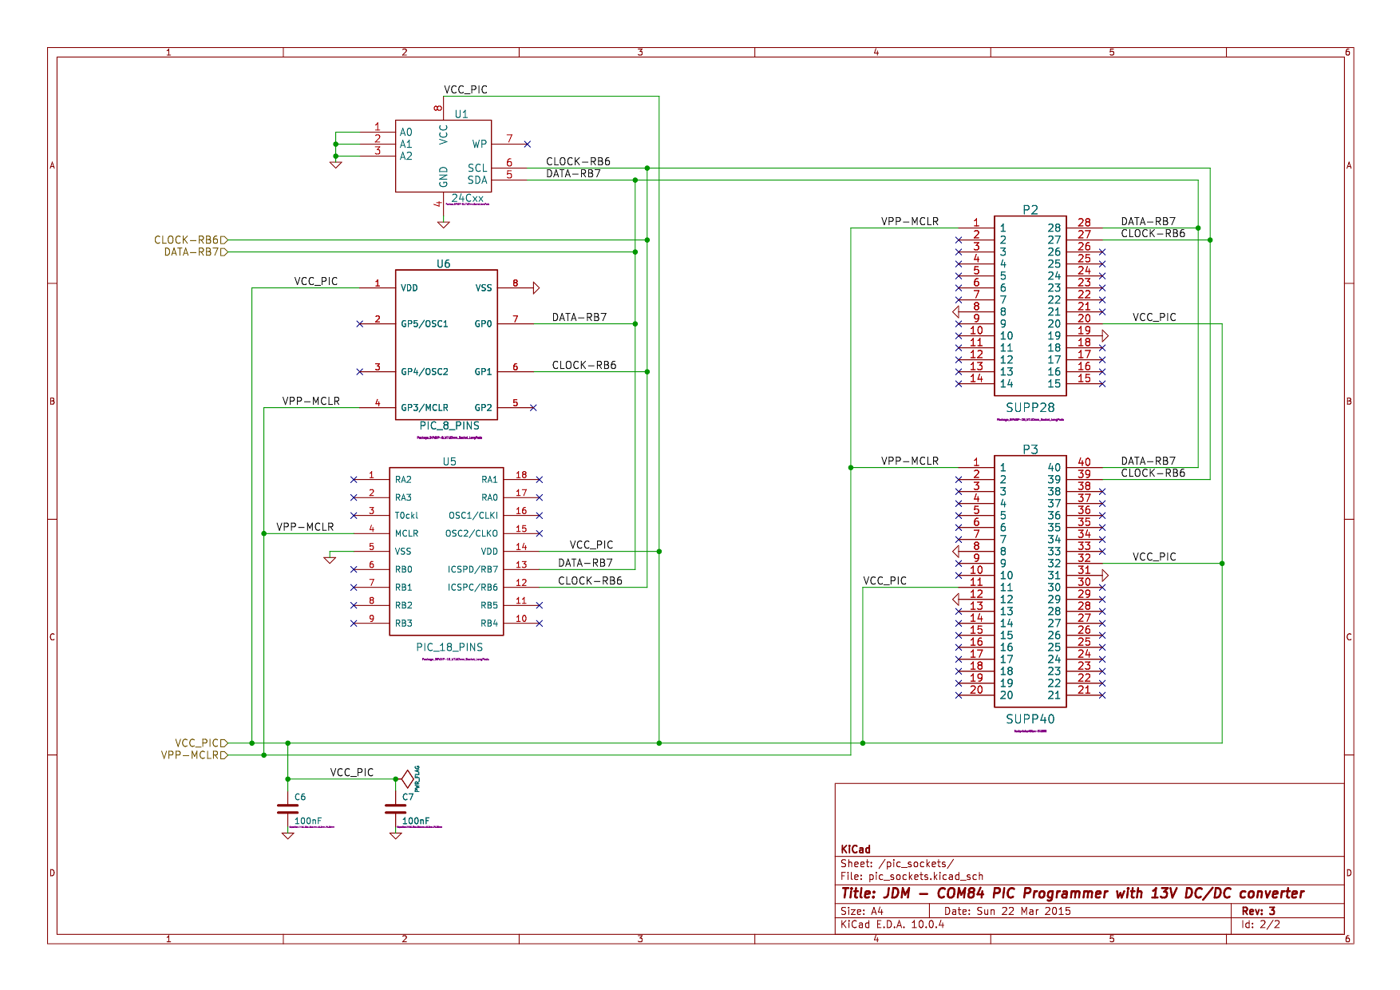
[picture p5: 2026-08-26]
manual-tests/real-designs/examples/pic_programmer/render/original-pic_programmer-pic_sockets.png

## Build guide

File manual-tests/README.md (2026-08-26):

# Manual testing

Sandboxes for exercising the CLI end to end, by hand, against a real git repository. The offline test suite (`npm test`) never calls an LLM, so the agent-loop paths (`do`, `create`, `sync` resolve) can only be observed here or in the gated integration tests.

## Prerequisites

- `kicad-cli` on your PATH (every command except `--help` checks for it)
- An API key in the environment for the LLM-backed commands: `ANTHROPIC_API_KEY` or `OPENAI_API_KEY`, or a saved-login provider (`--model codex`, `--model cursor`, `--model claude-code`)
- `npm install` done at the repo root

## Control boards

`manual-tests/reference-boards/` holds committed reference projects for the deterministic drafting engine, with symbols vendored from the real KiCad libraries. `npm run refboards` re-drafts each board, byte-compares against its reference, and renders a PNG for visual comparison; `npm run refboards -- --update` regenerates the references after a deliberate engine change. The byte contract also runs in CI (`test/draft-reference-boards.test.ts`). See [reference-boards/README.md](reference-boards/README.md).

## Real designs

`manual-tests/real-designs/` drafts boards nobody wrote for us, read from a local KiCad install, and puts the engine's drawing next to the one a person made of the same circuit. Nothing is committed and nothing is byte-compared: a human's schematic and the engine's are different drawings of the same netlist, so the netlist equality is checked by machine and the drawing by eye. `npm run realdesigns` runs the sweep into `manual-tests/runs/real-designs/`. See [real-designs/README.md](real-designs/README.md).

## Variants

Each variant materializes a self-contained git repository under `manual-tests/runs/` (gitignored). Run everything from the repo root.

### create: brief to full pipeline

An empty repository plus the USB-C breakout brief from `examples/simple/`. Tests Mode A: spec proposal, schematic, verification, output package.

```bash
./manual-tests/setup.sh create
npm run dev -- --repo manual-tests/runs/create create --brief examples/simple/usb-c-breakout.md
```

### edit: task on an existing project

A copy of the known-good `open-key` fixture project (U1, R1, R2, nets 3V3/GND/EN/GPIOx). Tests `init`, `check`, and the core `do` loop on real KiCad files.

```bash
./manual-tests/setup.sh edit
npm run dev -- --repo manual-tests/runs/edit init
git -C manual-tests/runs/edit add -A && git -C manual-tests/runs/edit commit -m "scaffold docs"
npm run dev -- --repo manual-tests/runs/edit check
npm run dev -- --repo manual-tests/runs/edit do "Rename the EN net to CHIP_EN and propagate the change everywhere"
```

Commit the scaffolded docs before `do`: it refuses a dirty tree, and a failed run rolls back with `git clean -fd`, which deletes untracked files.

Other things worth trying in the edit sandbox: `sync` after hand-editing a doc out from under the schematic, `do --dry-run`, `do --interactive`, and a task that violates a budget to see the refusal path (AC-3.4).

## Resetting

Pass `--fresh` to wipe and recreate a sandbox:

```bash
./manual-tests/setup.sh edit --fresh
```

Inspect what a run did via the sandbox itself: `git -C manual-tests/runs/edit log --stat`, `docs/DECISIONS.md`, `docs/CHANGELOG.md`, and the transcript under `.copperhead/runs/<ts>/`.

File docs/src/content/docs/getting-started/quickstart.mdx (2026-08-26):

---
title: Quickstart
description: Install copperhead, choose a model backend, and run your first verified change.
sidebar:
  order: 2
---

import { Steps } from '@astrojs/starlight/components';

:::tip[Agent Onboarding]
If you are working inside an AI coding assistant (like Claude Code, Cursor, or Codex), you can install and configure copperhead automatically for your repository with a single pasteable command:

```text
Install copperhead for this repo using https://raw.githubusercontent.com/copperheadhq/copperhead/main/agent-install-prompt.md
```
:::

## Requirements

- Node.js >= 20
- [KiCad](https://www.kicad.org/) >= 8, with `kicad-cli` on your `PATH`
- One model backend: an authenticated local Codex CLI, a logged-in Claude Code (saved login, no API key), or an OpenAI/Anthropic API key supplied through the environment
- A git repository (copperhead snapshots before it edits, and rolls back if verification fails)

Check that KiCad's CLI is visible, since every command probes it before doing anything:

```bash
kicad-cli version
```

## Setup

<Steps>

1. **Install the CLI.**

   ```bash
   npm install -g copperhead
   ```

2. **Choose a model backend.**

   To reuse your existing Codex login without a model API key:

   ```bash
   npm install -g @openai/codex-sdk   # optional adapter, loaded only for Codex runs
   codex login status
   export COPPERHEAD_MODEL=codex
   ```

   If `codex` is not on `PATH`, the SDK package includes a compatible launcher. For a global install:

   ```bash
   export COPPERHEAD_CODEX_PATH="$(npm root -g)/@openai/codex/bin/codex.js"
   ```

   To reuse a Claude subscription through your logged-in Claude Code, also without a model API key:

   ```bash
   claude setup-token                     # while logged into Claude Code
   export CLAUDE_CODE_OAUTH_TOKEN=...      # the token it prints
   export COPPERHEAD_MODEL=claude-code
   ```

   The Claude Agent SDK ships as an optional dependency, so a normal install includes it. See [Saved login (Claude Code)](/reference/configuration/#saved-login-claude-code).

   Or set a direct model API key. Keys are read from the environment only, never written to a config file, and redacted from transcripts.

   ```bash
   export ANTHROPIC_API_KEY=...   # or OPENAI_API_KEY
   ```

   Model selection resolves in this order: the `--model` flag, then `COPPERHEAD_MODEL`, then `model` in `.copperhead/config.json`, then whichever API key is present. See [Configuration](/reference/configuration/).

3. **Adopt an existing project.**

   Run `init` from the root of a repo that already contains a KiCad project. It reads the schematic, scaffolds the design docs, writes `.copperhead/config.json`, and installs a pre-commit hook.

   ```bash
   cd my-board
   copperhead init
   ```

   It is idempotent: rerunning it leaves your edits alone. If you have hand-edited a generated doc, `init` refuses to overwrite it and exits non-zero, telling you which files it skipped. Pass `--force` if you actually want them regenerated.

</Steps>

## Make a change

```bash
copperhead do "add an external key jack on a spare GPIO"
```

The agent reads the docs, proposes the change as a validated spec, edits the schematic and the docs together, then runs ERC and DRC until they pass. To see the proposal before anything is written:

```bash
copperhead do "..." --dry-run
copperhead do "..." --interactive   # pause for approval once the proposal validates
```

## Verify

`check` is contractually free of LLM calls and network access, so it is safe in CI and in a pre-commit hook. It runs ERC, DRC, doc-drift detection, constraint checks, and spec validation.

```bash
copperhead check     # alias: copperhead verify
```

It exits 0 when everything agrees and 1 when it does not.

## Next

- [Simple demo](/getting-started/demo/): the full create pipeline, one command
- [The agent loop](/concepts/agent-loop/): what one run actually does
- [Docs as memory](/concepts/docs-as-memory/): what lives in `docs/` and why
- [CLI reference](/reference/cli/): every command and flag

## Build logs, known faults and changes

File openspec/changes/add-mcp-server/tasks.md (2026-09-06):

# Tasks: add-mcp-server

## 1. Command-layer entry points

The entry points already exist and return structured results (`runCheck`, `syncVerify` / `syncResolve`, `runInit`, `runAgentLoop`); this section confirms they are usable from a non-CLI caller rather than refactoring them.

- [x] 1.1 Audit the four entry points for CLI-only coupling (direct `console` writes, `process.exit`, interactive prompts) and thread the existing injection points (log callbacks, AUTO marker) so a non-CLI caller gets the same structured result
- [x] 1.2 Golden test: the structured result each entry point returns is byte-identical to what the corresponding `--json` CLI path prints, so the server and the CLI cannot drift

## 2. Server

- [x] 2.1 Add `@modelcontextprotocol/sdk`; implement `src/mcp/server.ts` with stdio transport and the five tool registrations with versioned JSON schemas
- [x] 2.1a Build every tool result through the shared `ToolResult` envelope and `seal()` so redaction is inherited, not reimplemented; map failures onto the shared `ToolErrorKind` values
- [x] 2.2b Contain `copperhead_init`'s `path` input with `resolveInRepo` (AC-4.2), with regression tests for `../` and absolute paths
- [x] 2.2a Implement `copperhead_doctor`: no `kicad-cli` preflight (it reports a missing one as a failed check), keyless, read-only (design D10)
- [x] 2.2 Implement `copperhead_check` (no inputs; `fab`/`strict` deliberately absent until `check` accepts them) and `copperhead_init` dispatch
- [x] 2.3 Implement `copperhead_do`: AUTO marker, optional `dry_run`, progress notifications during the run, summary result (`committed`/`rolled_back`/`refused`, commit hash, files touched, verification, transcript path)
- [x] 2.4 Implement `copperhead_sync` with `resolve` gating
- [x] 2.5 Implement key detection using the shared `ToolErrorKind` values: `unavailable` when no key resolves (naming the env vars) and when two credentials make the choice ambiguous; keyless operation for check/init
- [x] 2.6 Implement per-repo serialization of mutating tools with typed busy error; concurrent check allowed
- [x] 2.7 Declare the unstable `copperhead-mcp/0.x` protocol version, announce experimental status on stderr at startup, and state instability in the server metadata
- [x] 2.8 Wire `copperhead mcp [--repo]` into the CLI with the experimental marker in its description and the bad-path error
- [x] 2.9 Assert stdout discipline for the keyless tools: a real stdio handshake plus `check`/`doctor` calls prove stdout carries only JSON-RPC. The `do` / `sync --resolve` paths are argued safe by construction (they pass `renderer`, which short-circuits the loop's only `console.log`) but are not covered by a test

## 3. Tests

- [x] 3.1 Protocol test over real stdio: handshake, tool list, and a `check` and `doctor` round trip against the pinned protocol version
- [ ] 3.1a Golden request/response fixtures, and a progress-notification test over stdio — `mcpRenderer` is unit-tested, but nothing asserts a notification actually reaches a host
- [x] 3.2 Parity test: `copperhead_check` result equals `check --json` on the same repo state
- [x] 3.3 Keyless degradation tests; serialization/busy test (asserted unconditionally, so deleting the lock fails it)
- [ ] 3.3a Rollback-as-result test: nothing yet asserts the delta spec's scenario that the working tree is byte-identical to the pre-run state after `rolled_back`. Needs a provider seam on `createMcpServer` to drive `copperhead_do` without a live model
- [x] 3.4 Surface audit test (required, not follow-up): enumerate registered tools and assert none accepts a filesystem path, drives a single loop step, or mutates files outside the gated pipeline
- [x] 3.4a Assert the five pipeline tool names resolve to nothing in the agent capability catalog, so the pipeline can never be invoked from inside the loop it runs (design D9)
- [x] 3.4b Assert a result carrying a fake API key in its text comes back redacted, proving the envelope path is actually used
- [x] 3.5 Assert the declared protocol version has a `0.` major and the startup notice names it, so dropping the experimental marker is a deliberate edit with a failing test behind it

## 4. Integrations and documentation

- [x] 4.1 Write the companion Claude Code skill under `integrations/claude-code/` (use copperhead tools, never edit `.kicad_*` directly); Codex equivalent or a documented gap note
- [x] 4.2 README: MCP section with host configuration snippets (Claude Code, generic stdio host), stating the surface is experimental and unstable
- [x] 4.3 Document the stabilization criteria (run-protocol handshake adopted, tool definitions built from the tool registry, one quiet minor) in `integrations/README` as the gate for registry submission

## 5. Deferred until stabilization

Not part of this change; listed so the gate is explicit.

- [ ] 5.1 Report the surface through `copperhead capabilities --json` and the `copperhead-run/<major>` constant; drop the local version constant
- [ ] 5.2 Submit registry listings (modelcontextprotocol servers repo, community registries); track links in `integrations/README`

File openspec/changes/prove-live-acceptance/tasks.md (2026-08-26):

# Tasks: prove-live-acceptance

## 1. Immediate housekeeping (Phase 0)

- [ ] 1.1 Fix the README version line to match `package.json` (0.3.0)
- [ ] 1.2 Implement `scripts/check-readme-consistency.ts`: version claim vs `package.json`, maturity block vs regeneration from `status.json`; wire into the offline CI workflow
- [ ] 1.3 Add `<!-- maturity:begin/end -->` markers and the initial generated maturity section; seed `status.json` from the current known state (AC-3.1/3.4/3.5/3.6 pass on OpenAI, others pending)

## 2. Nightly live workflow

- [ ] 2.1 Write `.github/workflows/live-acceptance.yml`: nightly schedule + `workflow_dispatch`, provider matrix, kicad-cli install step, `LIVE_ACCEPTANCE_ENABLED` toggle, missing-key legs marked `not_run`
- [ ] 2.2 Emit per-AC results into `status.json` (per provider, timestamps, retry/flake counts)
- [ ] 2.3 Badge matrix in the README fed by workflow status / `status.json`
- [ ] 2.4 Finish the AC-3.2 and AC-3.3 integration tests so the nightly suite covers all of AC-3.x (currently unwritten; blocks full matrix meaning)

## 3. Evidence promotion

- [ ] 3.1 Implement promotion: copy passing runs' redacted transcript + summary to `demo-runs/<ac-id>/`, replacing prior entries
- [ ] 3.2 Independent redaction re-check: grep candidates and full tree for `sk-[A-Za-z0-9_-]{20,}`, hard-fail on match (extends AC-4.1 to CI teardown)
- [ ] 3.3 Bot commit with `[skip ci]`, rebase-retry-then-PR conflict strategy; README evidence links per AC

## 4. Telegraph benchmark

> **Superseded by [copperbench](https://github.com/copperheadhq/copperbench), a separate repository.** The bespoke `traps.json` format is expressible in that suite's general assertion vocabulary, so Telegraph lands there as a task under the shared manifest rather than as a one-off runner here. Strike this section once that suite's runner exists; sections 1 to 3 and 5 are unaffected and remain in this repo's scope.

- [ ] 4.1 Pin the Open Telegraph brief under `benchmarks/telegraph/` and write `traps.json` (budget refusal, constraint citations, drift catches, gate events) with ids and transcript/repo-state matchers
- [ ] 4.2 Implement `scripts/benchmark-telegraph.ts`: scratch-directory `create` run, trap evaluation, per-trap output, non-zero on failure; `npm run benchmark:telegraph`
- [ ] 4.3 Commit format for benchmark results (trap outcomes + run summary, no full transcript); README benchmark section linking claims to trap ids
- [ ] 4.4 Run the benchmark live once per provider and publish the first results

## 5. Verification

- [ ] 5.1 Dry-run the workflow with keys in a fork/branch; confirm honest `not_run` behavior with a key removed
- [ ] 5.2 Confirm AC-4.1 grep passes over the whole tree including promoted evidence
- [ ] 5.3 Hand-edit inside the maturity markers on a branch and confirm CI fails (self-test of the drift check)

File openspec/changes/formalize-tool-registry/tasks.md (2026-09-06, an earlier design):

# formalize-tool-registry: Tasks

## 1. Envelope and registry (no behavior change)

- [x] 1.1 Add `ToolResult`, `ViewHint`, `ToolErrorKind`, `gate()`, and schema `version` types; add identity `defineTool` / `defineSkill` with skill default-gate conjunction
- [x] 1.2 Implement envelope helpers: `ok`/`fail` constructors, flatten-to-string for provider `Msg` content, redaction of `data`/`summary`/`detail`/`error.message` at construction via existing `redactSecrets`
- [x] 1.3 Implement `ToolRegistry` (`get`, `list(ctx)`, protocol version) wrapping the current `TOOLS` array with `gate: (ctx) => !requiresUnlock || ctx.editsUnlocked`
- [x] 1.4 Point `availableTools` / `dispatchTool` at the registry; preserve today's flattened strings including `"not available"` / `"unlock"` on a locked `edit_file` dispatch
- [x] 1.5 Unit tests: flatten, typed error kinds, redaction-at-construction (key-shaped token stripped before the object is returned)

## 2. Capability files and conformance

- [x] 2.1 Wrap existing handlers via `defineTool` in the barrel (`version`, `viewHint`, same handler behavior); skills stay one file each under `src/capabilities/skills/`
- [x] 2.2 Barrel `src/capabilities/index.ts`; `src/agent/tools.ts` keeps `RunContext`, dispatch, and the nested skill sub-run
- [x] 2.3 Conformance test: unique names, `version`/`viewHint` set, catalog tools match `HANDLERS`, barrel imports every `skills/` file, skill `tools` resolve, skill effective gate at least as strict as each declared tool, no skill lists `finish`
- [x] 2.4 `gating-sync` keeps `expect(list(ctx).map(e => e.name)).not.toContain('edit_file')` (and `write_file`); envelope `unavailable` assertion is additive; `"not available"` / `"unlock"` substrings still pass

## 3. Loop, providers, renderer

- [x] 3.1 Loop obtains the per-turn catalog from `registry.list(ctx)`, records the envelope on the transcript, flattens for the provider `Msg`
- [x] 3.2 Providers keep sending `{ name, description, parameters }`; `parseToolCalls` catalog `Set` still comes from `list(ctx)` (off-catalog stays prose)
- [x] 3.3 `theme.ts` / `render.ts` / `dock-renderer.ts` read `result.ok` and `viewHint`; delete the pass/fail regex heuristic in `toolLine`
- [x] 3.4 Retry: `validation`/`refusal`/`unavailable` are not retried; `exception` uses `src/util/retry.ts`
- [x] 3.5 Render-path redaction test: a handler payload containing `sk-` or a `*_KEY` env value never appears in the renderer input or the printed tool line

## 4. Nested sub-run

- [x] 4.1 Extract a nested turn-loop path that shares parent ledger/transcript/`editsUnlocked`, applies a tool-name subset and `maxTurns`, and does not git-snapshot, commit, or `openspec archive`
- [x] 4.2 Nested path never consults `finishRequest` for commit; `finish` is not placed in a skill child catalog
- [x] 4.3 Dispatch of a skill name runs the nested path and returns one envelope to the parent
- [x] 4.4 Tests: parent records one tool result per skill call; no extra commit / archive; parent `finishRequest` unchanged after the skill returns

## 5. generate_report and CLI

- [x] 5.1 Register skill `generate_report` (`scope: power|all`, default `all`, `maxTurns` 8, tools `read_file`/`search`/`list_nets`/`run_erc`/`run_drc`/`export_svg`/`check_drift`, no mutation tools); report is the envelope, no report file written
- [x] 5.2 CLI `copperhead skill list` (LLM-free, network-free) and `copperhead skill run <name>` (kebab CLI name maps to underscore catalog name)
- [x] 5.3 `skill run` missing-key path: non-zero exit, env var or login named, no stack trace; unknown name: non-zero, name in the message
- [x] 5.4 Export a runner that tests invoke with a `ScriptedProvider` so `skill run generate-report` is covered offline
- [x] 5.5 `copperhead --help` lists `skill`

## 6. Scenario tests (map 1:1 to delta specs)

- [x] 6.1 tool-registry: combined catalog; dispatch picks skill tier; unknown name → `unavailable`; every entry versioned; successful flatten; locked `edit_file` flatten; validation not retried
- [x] 6.2 tool-registry: locked list omits edit tools; unlock is presence; default skill gate hides locked skills; `generate_report` present while locked; weaker skill gate fails conformance; no skill lists `finish`
- [x] 6.3 tool-registry: parent sees one envelope; nested run is not a `do`; always-available / cannot-write / report-is-envelope for `generate_report`; unregistered file fails CI; unique names
- [x] 6.4 spec-gating: pre-validation list; unlock after validate; absence-from-list is the invariant; skill cannot smuggle `edit_file`; gating-sync has both assertions
- [x] 6.5 agent-core: provider still sees strings; off-catalog stays prose; inner turns do not commit; nested finish cannot satisfy the parent
- [x] 6.6 cli-surface: help lists `skill`; `skill list` LLM-free on the fixture; `skill run generate-report` with ScriptedProvider; run without a key; unknown skill
- [x] 6.7 safety-rails: key-shaped token never reaches the renderer; transcript still redacted; `check` module-graph guard excludes `src/capabilities/` and provider SDKs (AC-2.1)

## 7. Docs and archive prep

- [x] 7.1 Draft SPEC.md edits for archive time: §4.2 becomes the two-tier catalog (existing tools + `generate_report`); §3 gains `skill list` / `skill run`
- [x] 7.2 README: document `copperhead skill list` / `skill run generate-report` and that `create` stages are not yet skills
- [x] 7.3 Confirm `STAGES` in `src/commands/create.ts` is untouched; run typecheck, build, and the offline suite; document environment-only failures honestly

## 8. PR #255 review fixes

- [x] 8.1 Contain skill-provider exceptions inside dispatch and apply bounded timeout plus 429 recovery to nested provider turns
- [x] 8.2 Give diagnostics handler-owned outcomes so failing ERC/DRC/drift/symbol/legibility results cannot render a success glyph
- [x] 8.3 Preserve partial unsuccessful report detail and every repeated inner tool call in call order
- [x] 8.4 Keep `skill list` filesystem-side-effect-free and give off-list skill calls an accurate unavailable reason
- [x] 8.5 Clone registry entries before binding default gates; cover weak gates, singleton isolation, refusal, JSON, no-provider, nudge, exception, retry, timeout, partial, and repeated-result paths
- [x] 8.6 Re-run typecheck, focused tests, full offline suite, build, and `openspec validate formalize-tool-registry`; document environment-only failures honestly

## 9. PR #255 second-round review fixes

- [x] 9.1 Close the provider `skill run` created on every exit path (`runSkillCli`), so no saved-login working directory or subprocess outlives the command
- [x] 9.2 `verify_symbols` reports `ok` from real mismatches, not from the unverifiable `no-library` bucket
- [x] 9.3 Conformance asserts the property that matters — a skill present in `registry.list(ctx)` has every declared tool's gate open — instead of the declared `ownGate`
- [x] 9.4 Availability test brackets its singleton gate swap so no assertion can leak it; drop the dead `isRetryableToolKind` export (retry policy stays pinned by the 429/exception dispatch test)
- [x] 9.5 One `MAX_TURN_TIMEOUTS` constant shared by the main loop and the nested sub-run
- [x] 9.6 Re-run typecheck, build, full offline suite, and `openspec validate formalize-tool-registry`

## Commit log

2026-08-08 fix(draft): keep edge-facing label text inside the frame
    The band budget now reserves each group's facing-label extents, and the
    final centering shift clamps against the true content extent with label
    text boxes included. On a sheet banded near the full usable width, the
    leftmost column's left-facing labels no longer overhang the frame:
    stickhub goes from 1 out-of-frame finding to 0 (367 before banding).
    Both changes are no-ops when the sheet has slack, so unbanded layouts
    and the pinned reference goldens are untouched.
    #220 phase 1; closes the out-of-frame half of #219.
2026-08-08 fix(draft): clear the residual text collisions with three guarded fallbacks
    Three mechanisms, each a fallback that fires only when the existing
    passes leave text colliding, so clean boards stay byte-identical:
    - power-value sweep: the power pass places its value text before any
    signal label exists, so whichever mover ran last was blind to the
    other. The value text has no electrical meaning, so it now moves LAST,
    with the finished sheet as its obstacle set.
    - label rides get a shorten rung and a deeper budget (4 to 8 units): a
    facing pair in a tight channel can only separate by retreating, and a
    bottom-pin label must clear the routing channel under its connector.
    - a vertical stub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
2026-08-08 test(manual): refresh examples with collision-free label placement
    Redrafted with the phase-1 and phase-2 fixes from #220. Error-severity
    findings: interf_u 13 to 0; cm5_minima 20 to 1 (the cross-group label
    leak tracked for phase 4); royalblue54L_feather 3 to 1 (its survivor is
    a pre-existing wire-through-symbol on L1, untouched by the text passes).
    [board.kicad_sch]
2026-08-08 fix(draft): a netless pin is still a connection point the router must avoid
    touchesForeign skipped any pin the intent names no net for, treating it
    as harmless. But bare copper still joins in KiCad: a wire through such a
    pin connects it. jetson-agx-thor-baseboard, drafting for the first time
    since banding (de5aa02), put a wired net's L-corner exactly on J14.46, a
    single-pin group the intent never names, and shipped a merged net past
    every gate: the corpus round-trip reported lost=1 gained=1. Pre-existing
    on this branch, exposed by banding, found by the gated corpus test.
    Netless pins now guard their point (there is no stub to predict for
    them). Stricter only, and no current board routes thr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
2026-08-09 feat(draft): compact mostly-empty sheets onto smaller papers
    Two structural causes put drafts on sheets sizes above the human's, most
    of them air: a depth whose parts stack into ONE full-height column, and
    a paper pass that accepts the first sheet the natural ribbon fits
    without asking how much of it is used.
    - placeAllGroups gains a column HEIGHT budget, the vertical analog of
    banding: a too-tall depth splits into side-by-side columns, in row
    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
    [board.kicad_sch]
2026-08-09 fix(draft): close the remaining frame overhangs the corpus sweep found
    Measured before/after across all fifteen demo projects surfaced three
    residual frame leaks the earlier passes missed:
    - shelf-wrap rows now reserve the flanking groups' label extents, the
    wrapTo analog of the band budget's reservation: complex_hierarchy hung
    three row-leading labels outside the left frame edge on a row filled
    to the full usable width.
    - the frame clamp measures power VALUE text too: the sweep may slide a
    rail name past its group rect's margin, and pic_programmer put one
    1 mm over the top edge of its freshly compacted sheet.
    - the clamp corrects the far edge FIRST, so its whole-unit rounding can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
2026-08-09 feat(export): add circuit-json export as a second draft backend
    Implements openspec change add-circuit-json-export (issue #231): a
    derived read-only tscircuit circuit-json view of a drafted schematic,
    serialized from the validated intent (source layer) and the engine's
    placement model (schematic layer). New `copperhead export circuit-json`
    sits beside `export bom` with the same deterministic, LLM-free,
    network-free contract; it refuses non-drafted or stale sheets by
    re-drafting the intent and requiring a byte-match with the on-disk
    schematic. Output is validated in tests against the exact-pinned
    `circuit-json` package's Zod schemas. Per issue #178, circuit-json never
    enters the mutation path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
2026-08-09 fix(export): place circuit-json schematic ports per multi-unit instance
    A multi-unit part places several EmitSymbol instances under one ref, each
    carrying only its unit's pinNumbers; the serializer previously collapsed
    them to one position. Emit one schematic_component per placed instance
    and anchor each schematic_port at the instance that draws its pin, using
    the unit view's local pin coordinates. Also dedupe the part-level pin set
    by number (de Morgan alternates repeat pins).
2026-08-09 docs(export): clarify the circuit-json staleness gate compares KiCad text, not two circuit-jsons
2026-08-09 feat(draft): passive banks chain on one trunk, and supply names classify power (#233)
    The stacked-passive idiom, in five connected pieces:
    - rail-bank trunks: two-pin parts adjacent on the same power net chain
    on one trunk — a stub per pin, joins between consecutive stub ends,
    ONE power symbol and value per run. Structural, not name-based, so the
    embedded renamed cap symbols real boards carry qualify, and so does a
    hand-drawn-style pull-up array. Every join is vetoed by touchesForeign,
    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
    [board.kicad_sch, buck-12v-5v.kicad_sch, ldo-demo.kicad_sch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]
2026-08-09 fix(export): emit one schematic_trace per contiguous wire chain
    Renderers (circuit-to-svg, circuitjson.com) draw a schematic_trace's
    edges as one connected route, so a per-net trace containing disjoint
    branches renders phantom diagonals between branch endpoints. Union-find
    wire endpoints per net and emit each contiguous chain as its own trace.
2026-08-09 fix(export): scale schematic coordinates to tscircuit grid units
    tscircuit renderers size text and ports in their unit system (grid step
    0.2 units); raw KiCad millimeters made every sheet render with ~13x-too-
    small text. Map one 100 mil grid step (2.54 mm) to one 0.2-unit step in
    the single toCj helper, scaling component sizes with it.
2026-08-22 feat(kicad): discover kicad-cli from standard Windows installation paths
    - probe standard Windows KiCad directories (e.g. C:\Program Files\KiCad\<version>\bin) when not on PATH
    - prioritize highest installed version in descending order
    - provide platform-tailored hints in KicadCliMissingError and KicadCliBadOverrideError
    - align doctor KiCad version check to >= 8 and add regression tests
2026-08-22 fix(kicad): enforce minimum version and correct CLI hints
2026-08-22 fix(kicad): reject unparseable CLI versions
2026-08-24 fix(kicad): address PR #244 review findings
    Finding 1 (medium): add MIN_KICAD_MAJOR floor to Windows version
    discovery in defaultFallbackBinaries(). Version directories below the
    minimum (e.g. 7.0) are now filtered out before probing, so a machine
    with only KiCad 7.x installed gets KicadCliMissingError instead of
    silently running ERC/DRC on an unsupported binary. Export
    MIN_KICAD_MAJOR from cli.ts so tests can import and assert it.
    Finding 2 (medium): add a block comment to MIN_KICAD_MAJOR in
    doctor.ts making explicit that kicadCheck() returning status: fail for
    KiCad below 8 and for unparseable output is intentional user-visible
    behavior, not a one-word hint-string correction.
    Finding 3 (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
2026-08-24 fix(kicad): refine Windows hint label and ENOTDIR test assertions
    - Update KicadCliBadOverrideError hint for Windows from 'PowerShell/cmd' to 'PowerShell' since Test-Path is PowerShell-specific
    - Assert direct unversioned candidate generation from defaultFallbackBinaries on ENOTDIR fallback root in test
2026-08-25 fix(kicad): dedupe MIN_KICAD_MAJOR and harden dedup regression test
2026-08-25 test(kicad): tighten PowerShell/cmd hint assertion to check entire remedy array
2026-08-26 fix(draft): anchor wired labels on their own run, and narrow the supply-name fallback
    Review findings on #224, in four parts.
    - A wired-net label could anchor on no wire at all. `wiredLabels.pts` is
    sorted for anchor preference, and the interior-point fallback walked it
    as if the sort had preserved pairing, so it interpolated between two
    corners that share no wire. KiCad attaches a local label only where it
    lies on a wire, so the net silently carried whatever name KiCad invents
    instead of the one the IR gave it. Three corpus nets shipped that way:
    Net-(F201-Pad1), Net-(U8-BIN) and Net-(U8-RIN), each anchored off every
    wire of its own run. The record now carries the run's SEGME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
2026-08-26 fix(draft): mark only a power class taken from the net name
    The `~` marker added alongside the classification basis fired on every net
    whose basis was `name`, and a signal is what a net is when nothing said
    otherwise: a net reaching no power_in/power_out pin and matching no supply
    shape defaults to signal with a `name` basis, so an ordinary board rendered
    `SDA=signal~, SCL=signal~, RESET_N=signal~` and dragged the legend along
    with it. A mark on almost every entry tells a reader nothing.
    The marker now means what it was meant to mean: a POWER class asserted from
    the net's name alone, which is the one classification no pin attests and the
    one an IR `kind` declaration exists to correct. Repor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
2026-08-26 docs(openspec): archive deterministic-schematic-drafting
    The change is implemented and shipped: the drafting engine computes
    placement, routing, power symbols, and group boxes from the netlist
    intent; the legibility checker gates drawing quality read-only; the
    scorer reports a composite advisorily.
    Archiving merges its delta specs into SPEC.md, per this repo's
    single-spec convention rather than a per-capability layout it has
    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
2026-09-04 fix(legibility): measure free text at its declared justification
    A free (text …) item was measured as centred on its anchor whatever its
    effects said. The engine's group captions are written `justify left top`,
    so at full sheet width the checker flagged a caption 12 mm inside the frame
    as outside it (esp32-amp, A1). The sheet reader now keeps a text item's
    horizontal and vertical justify, and textBounds anchors the box accordingly;
    symbol property text keeps the centred measurement, whose justification is
    relative to the symbol's own rotation and mirror.
2026-09-04 fix(draft): compact honestly, lead with the IC, and keep text inside its box
    The schematic stage shipped a 286-symbol sheet as one ribbon on A0 at 7% ink
    utilization with an empty notes list. Four engine defects, each with a gate:
    - The decoupling bank sat outside the column-height budget, so compaction
    could not shorten the tallest group (A1 missed by 8 mm), and a failed
    compaction restored the ribbon silently. The bank's rows now count against
    the budget and may widen under it; a failure pushes a note with each
    sheet's closest miss; the report carries a `sheetFit` verdict.
    - Same-depth parts stacked into one full-height strip beside a short IC.
    Columns of four or more cells bala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
    [buck-12v-5v.kicad_sch, ldo-demo.kicad_sch, npn-switch.kicad_sch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]
2026-09-04 feat(score): measure wiring style, and score any sheet on one scale
    The scorer could not tell a resistor wired to its IC pin from one hung on
    two labels, and it capped every hand-drawn sheet at 40 for lacking group
    boxes. Four metrics now follow wires from every placed pin, through endpoint
    and T joins: pin-attachment, island-parts, power-symbol-economy and
    labels-per-part. Attachment and islands join the gated composite at modest
    weight; a wiring-style composite built from the four plus crossings per wire
    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
2026-09-04 feat(draft): hang a part on the pin it serves (#220 phase 3, first piece)
    A drafter puts a part on the pin it serves: the compensation network off
    COMP, the bootstrap cap on BOOT, a pull-up rising from the pin it pulls.
    Column placement put every such part in a column of its own and let the
    wire pass decide later, so most ended as labelled islands: the reference
    boards attached 14 to 53 percent of their two-pin parts where a person
    attaches 90 or more.
    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
    [buck-12v-5v.kicad_sch, npn-switch.kicad_sch, tierC-board.kicad_sch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]
2026-09-04 feat(draft): series parts on the row, symbol rotation, local runs wired
    Read against a hand-drawn reference (Sonocotta Louder-ESP32 H6): series
    resistors lie along the pin row between label and pin, the output filter
    runs along the OUT rows, bootstrap caps sit at their pins, and a local run
    is wired even where the net also goes elsewhere. Three rules close most of
    that gap:
    - Symbol rotation. A placed instance carries its rotation and a rotated
    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
    [buck-12v-5v.kicad_sch, ldo-demo.kicad_sch, npn-switch.kicad_sch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]
2026-09-05 feat(draft): colour nets by function and hang test points beside their net
    Wires and labels now carry a colour by net class and prefix family: every
    rail one colour, every ground another, and each family of two or more
    signals sharing a prefix (I2S_, SPI_, BTN_) a colour of its own from a
    fixed palette. One-pin test points whose net reaches an IC side pin hang
    above that pin's row and are wired to it. The stage-4 prompt asks for
    prefix-named buses, +/- or P/N differential pairs and values with units,
    and the drafting docs carry the convention table with each rule's owner.
    Conventions taken from the KiStack kicad-schematic skill checklist; its
    image-iteration method is what the engine replac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
    [buck-12v-5v.kicad_sch, ldo-demo.kicad_sch, npn-switch.kicad_sch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]
2026-09-05 docs(site): restyle the docs after GitBook's clean theme
    Modeled on docs.quilter.ai, still on Astro Starlight so search, edit
    links, and the llms.txt plugin keep working.
    - Neutral near-black palette in both modes, copper kept as the accent
    - Inter Variable and IBM Plex Mono, self-hosted via fontsource
    - Sidebar: floating rounded panel, uppercase group labels, per-page
    icons, tinted pill on the active item, pinned version footer
    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
2026-09-06 fix(agent): close skill-run providers and stop reporting unverifiable as failure
    Second round of PR #255 review fixes.
    `copperhead skill run` built a provider and exited without closing it. The
    agent loop closes providers in a `finally` for a reason -- `close()` removes
    the saved-login backend's mkdtemp working directory and aborts its subprocess,
    and skipping it is the I8 disk-fill mode. `skill run` has no agent loop to
    inherit that from, so the lifecycle now lives in `runSkillCli`, which brackets
    the run (including the unknown-skill throw path) and warns rather than losing
    the result when `close()` itself throws. The CLI action carries an exit code
    out instead of calling `process.exit` in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
2026-09-06 docs(site): fix review findings on the GitBook-style theme
    Addresses the automated review on #271.
    - Printing rendered the dark palette. Starlight's print.css is unlayered
    too, so it tied with this file's :root on specificity and lost on
    document order, and a dark-mode reader printed light text on a
    near-black page. A @media print block at the end of custom.css restores
    the light values, listing [data-theme='dark'] so it wins in both modes.
    - Footer focus order did not match the screen. The pagination cards were
    moved above the meta row with CSS `order`, which leaves DOM and tab
    order alone, so tabbing past the content jumped to "Edit page" at the
    bottom and then back up the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
2026-09-06 feat(mcp): serve the gated pipeline to MCP hosts over stdio (#40)
    Coding agents are already pointed at KiCad repos through generic file
    tools, so a host agent can rewrite a .kicad_sch with no spec gate, no
    verification and no rollback. copperhead's invariants only protected
    people entering through the CLI. `copperhead mcp` extends them to any
    MCP host.
    The security boundary is tool granularity, not prompt wording. The
    server exposes five opaque, outcome-level tools — copperhead_check,
    copperhead_do, copperhead_sync, copperhead_init, copperhead_doctor —
    and nothing finer: no file-edit tool, no raw KiCad tool, no way to
    drive one step of the loop. No sequence of MCP calls can skip
    spec-ga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
2026-09-06 fix(mcp): contain the init search path, and address review findings
    The review's blocking finding: `copperhead_init`'s `path` input escaped the
    repo sandbox. `runInit` resolved it with bare path.resolve rather than
    resolveInRepo — whose docstring says "All file tools must go through this"
    — so `{path: "../foreign"}` scaffolded this repo's docs from a foreign
    project and durably wrote an out-of-repo config.schematic that every later
    check/do would then operate on. Worse, draft_schematic *writes* to that
    path, and rollback (git reset --hard + clean -fd) only covers repoRoot, so
    a clobbered out-of-repo schematic had no rollback at all.
    Until this change that input was reachable only from a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
